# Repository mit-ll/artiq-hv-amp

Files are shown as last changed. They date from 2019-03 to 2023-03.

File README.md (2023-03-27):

# artiq-hv-amp

Schematic designs for a 1U rack mountable amplifier for the Zotino and Fastino. 

These are from the sinara family of DACs (https://github.com/sinara-hw/Zotino, https://github.com/sinara-hw/Fastino) and output 32 channels from -10 to +10 V and offer similar capabilities to the underlying AD9910 and AD9912 DACs from analog devices on which these cards are based. The amplifiers in this repository provide the following capabilities:

1. x4 amplification based on Linear's LTC6090 low noise HV amp.
2. Differential pair routing and differential inductors on all outputs.
3. MHz bandwidth and low output impedance.
4. Differentially paired HD68 input/output compatible with zotino, fastino.
5. ESD protection on all outputs with high speed low capacitance diodes.
6. Reverse polarity protection on high voltage input power.

DISTRIBUTION STATEMENT A. Approved for public release. Distribution is unlimited.

This material is based upon work supported under Air Force Contract No. FA8702-15-D-0001. Any opinions, findings, conclusions or recommendations expressed in this material are those of the author(s) and do not necessarily reflect the views of the U.S. Air Force.

© 2022 Massachusetts Institute of Technology.

Delivered to the U.S. Government with Unlimited Rights, as defined in DFARS Part 252.227-7013 or 7014 (Feb 2014). Notwithstanding any copyright notice, U.S. Government rights in this work are defined by DFARS 252.227-7013 or DFARS 252.227-7014 as detailed above. Use of this work other than as specifically authorized by the U.S. Government may violate any copyrights that exist in this work.

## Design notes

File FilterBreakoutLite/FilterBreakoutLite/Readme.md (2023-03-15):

This folder contains KiCAD models of filter boards for use with DAC signals arranged in groups of 32 differential pairs in an HD-68 cable.
Jules designed the original and manufactured it for Marlo and I (dreens) made more recent modifications to extend to the rest of the LL ions lab.

Key organizing principles:
1. A 'motherboard' takes 32 pairs as input, and offers a number of jumper selectable options.
2. One option is to utilize 8 four channel daughter boards inserted via card edge connectors.
3. Another option is to use on-board low-pass filters with 10 kHz cutoff and 12 dB/octave rolloff.
4. Coax pickoffs enable monitoring or over-riding channels on a case by case basis.
5. Grounds can be passed through to an HD-68 differential output, or shorted to board ground.
6. Filtered signals may be accessed either at this output HD-68, or via a DB-25 connector with the first 25 channels.
7. The FilterMotherboard folder contains the latest motherboard as well as some low-pass daughterboards, which weren't produced in light of the on-board LP option that was added.
8. The FilterDaughterboard-old folder contains daughterboards useful for shuttling with a higher cutoff frequency.

Known Issues:
1. The DB-25 output connector has a left-right mirroring issue. Best to resolve using ribbon cable to connect out to enclosure.
2. There's not really a way to utilize the 32 pin differentially paired output right now.
   One could imagine a future where we run differential pairs all the way to the octagon / internal vacuum circuitboard.
3. Be sure to review CAD related issues below.

CAD for the enclosure:
1. Successfull 1U rack mount ordered from protocase.
2. Key issue: rear screws off by exactly 0.5"- too close to the front panel by this amount.
3. Key issue: needs rear panel re-design for DB25 style cases instead of COTIAC mil-spec 32 pin.
4. Key issue: needs to be updated for 2U height for use with card-insertable motherboards.
5. This will entail obtaining a new template from protocase (the included design has as its base an imported model from protocase).

Ordering from protocase:
1. I've had success with two options so far, powder coated steel, and aluminum. Former is a bit cheaper but latter is a bit better.
2. Make sure to utilize their "PEM" fasteners as done here- these are self-clinching fasteners that can make board installation a breeze.
3. PEM CAD available from PENN engineering, also cross check protocase' list of in-stock PEMs.
4. Ask for the case to be powdercoat screened in a few places to ensure electrical connectivity across all panels.
5. They'll want you to proof everything.

Ordering boards from advanced circuits:
1. I can't remember right now. Bug me (dreens) and I'll dig up my order documentation. I had them do assy too which was great.

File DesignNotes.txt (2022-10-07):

Specs of the Zotino (https://github.com/sinara-hw/Zotino/wiki):
>Output impedance of DAC is 500ohm with 2.2nF in parallel
>Output amplifier: OPA197
>All together, the output of the DACs has a 3rd-order Butterworth response with 75kHz cutoff frequency

Options for amplifier:
>OPA454 [296-41370-1-ND] //highest voltage
>OPA542 [296-15965-1-ND]
>OPA445 [OPA445AU-ND] //the one from the old LL design

>D-Sub connector:
>>5787082-7 [A31814-ND]

General thoughts:
>Would it be possible to use a boost converter and drive the amps directly from the output of the Zotino?
>>Could check out the schematics for the Zotino to see how this is done without getting too much noise
>>[LT3471EDD#TRPBFCT-ND]

---

General notes about using KiCAD:
>Select a component and go to properties; from here you can edit the library reference to change the library that the symbol derives from
>http://docs.kicad-pcb.org/5.1.0/en/getting_started_in_kicad/getting_started_in_kicad.html
>It would appear that setting up the libraries I have done, by using path substitutions in (Preferences>Manage symbol libraries...) has succeeded in making the project portable

Still ToDo:
>[CRITICAL] Figure out if it's possible to have hierarchical layouts similar to the schematics
>>>https://forum.kicad.info/t/hierarchical-sheets-and-pcb/6053/5
>>>The trick seems to be to use the standalone version of the PCB editor, which allows you to append board designs with other PCB files.  Unclear how much time this is really going to save for me, but should look in to it.
>Figure out the best default connection for the unused pins of the OPA454
>[OPTIONAL] Figure out how to make a nice 3D model of the HD68 connector
>>>https://forum.kicad.info/t/where-to-start-with-3d-models-for-custom-parts/7185

Other links:
>https://forum.kicad.info/t/how-to-make-kicad-schematic-libraries-load-with-a-relative-path/2639/3
>https://learn.sparkfun.com/tutorials/beginners-guide-to-kicad/setting-up-schematic-component-libraries
>https://hackaday.com/2017/05/18/kicad-best-practises-library-management/

---

Notes from dreens:
-I've added protection diodes to the design- first of all polarity protection diodes on the power supply, and also 70 V steering diodes on the input to the amplifiers. 
-I wasn't able to protect the output for lack of high enough voltage diodes in a small enough form factor.
-I've also added u.FL pickoffs before the input to the amplifier to enable network analysis of the transfer function through the amps for shuttling predistortion computations.
-PCB Unlimited had trouble getting the differential chokes to solder. Something about the feet not being exposed enough? 
-I guess maybe they're laser heating the pads and couldn't get it to heat enough.

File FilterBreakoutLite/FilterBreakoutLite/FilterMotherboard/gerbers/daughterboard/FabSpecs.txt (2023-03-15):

Total layers = 4
Board dimensions = 1.05" x 1.11"
Board type = FR4
Board thickness = 0.062"
Outer copper wt. = 1.0 Oz
Inner copper wt. = 1.0 Oz
Min trace/space = 0.010"
Min hole dia. = 0.015"
Min annular ring width = 0.007"
Total drills = 20
Surface finish = Lead-free HAL with selective hard gold, 30 microinch (see GerberList.txt for selective gold layer)
Soldermask both sides = yes
Soldermask type = LPI
Soldermask color = green
Silkscreen color = white

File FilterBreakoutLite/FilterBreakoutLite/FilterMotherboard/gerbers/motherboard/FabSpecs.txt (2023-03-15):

Total layers = 4
Board dimensions = 4.21" x 2.72"
Board type = FR4
Board thickness = 0.062"
Outer copper wt. = 1.0 Oz
Inner copper wt. = 1.0 Oz
Min trace/space = 0.005"
Min hole dia. = 0.010" (can be microvias)
Min annular ring width = 0.005"
Total drills = 332
Surface finish = Not critical; use default
Soldermask both sides = yes
Soldermask type = LPI
Soldermask color = green
Silkscreen color = white

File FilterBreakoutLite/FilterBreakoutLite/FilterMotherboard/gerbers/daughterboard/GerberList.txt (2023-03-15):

File extension		Description

GM1			Board edge

DRL			Drill

GTL			Top Copper
G2			Interal layer #1
G3			Internal layer #2
GBL			Bottom Copper

GTG			Top selective gold
GBG			Bottom selective gold

GTS			Top soldermask
GBS			Bottom soldermask
GTO			Top silkscreen
GBO			Bottom silkscreen

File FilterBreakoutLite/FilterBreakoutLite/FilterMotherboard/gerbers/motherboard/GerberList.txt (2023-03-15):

File extension		Description

GM1			Board edge

DRL			Drill

GTL			Top Copper
G2			Interal layer #1
G3			Internal layer #2
GBL			Bottom Copper

GTS			Top soldermask
GBS			Bottom soldermask
GTO			Top silkscreen
GBO			Bottom silkscreen
GTP			Top paste	
GBP			Bottom paste

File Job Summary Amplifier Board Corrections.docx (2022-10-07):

Job: Update KiCAD amplifier schematic and prep BOM for assembly April 5th, 2022

Notes:

This work was completed by Arham one month ago, but key problems with the work were just discovered.

Tasks:

1. Two polarity reversal protection diodes were added. EGP51G-E3/CGICT-ND. As originally requested, “One should point from -V to ground, the other from ground to +V.”
  a. This task is not done correctly. The diodes have been added in series, which would create an unwanted diode drop on the power supply lines.

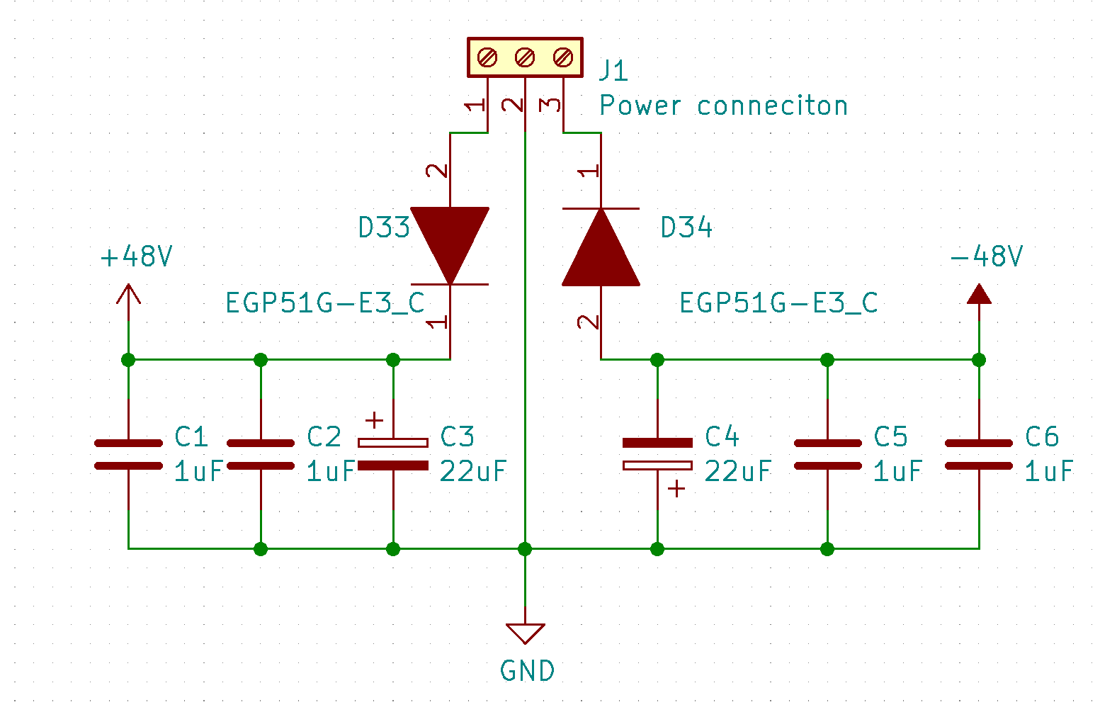
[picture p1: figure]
Machine generated alternative text: +48V EGP51G-E3 C 000 22uF GND Power conneciton EGP51G-E3 C 22uF

  b. They need to be in parallel with the buffer capacitors, in the reverse direction so as to ground the incorrectly applied voltage:

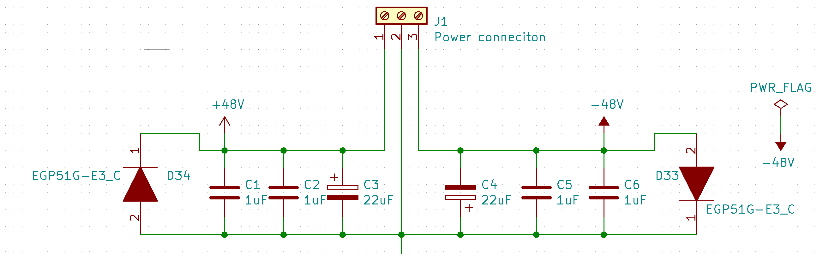
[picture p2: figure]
Machine generated alternative text: Power conneciton EGP51G-E3_C 000 +48V 22uF FLAG 22uF EGP51G-E3 C

2. On several of the blocks, copper pours did not connect properly. I count 11/32 channels with this problem.

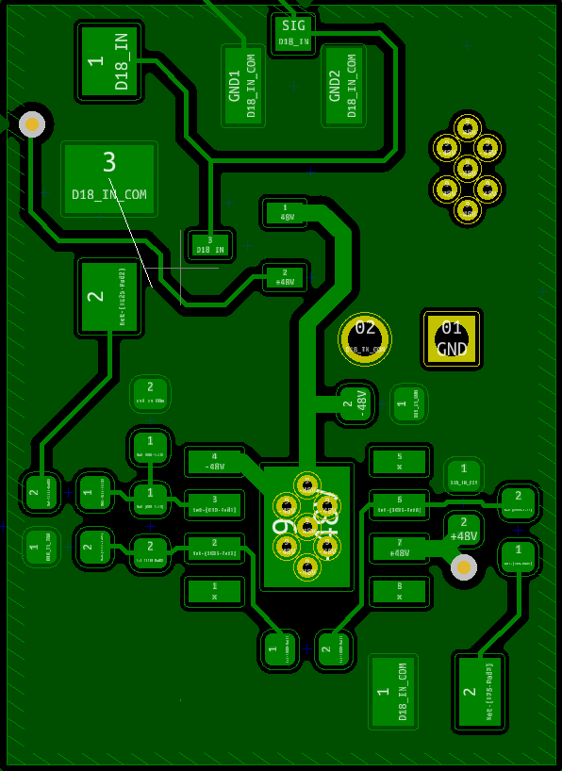
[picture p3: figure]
Machine generated alternative text: DIB 1 com

  a. Note the white line connecting from the #3 to the dangling pour. These white lines are always a sign of disconnected things and I’m not sure how they were missed.
  b. Note that one of the devices even grounds to this region of the copper pour, and thus will not function properly.
  c. Here is another example on the other side of the board:

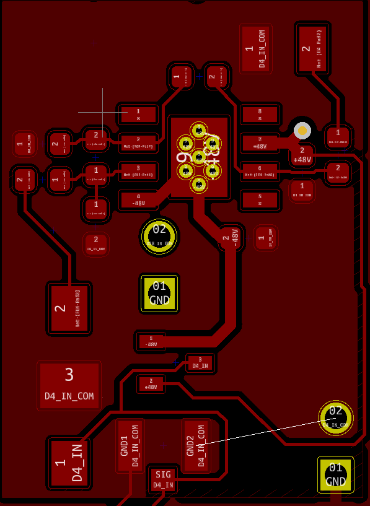
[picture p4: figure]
Machine generated alternative text: +48V +48V D4 IN com SIG

  d. See the white line connecting the left portion of the pour to the right portion. In this case, the bypass capacitors are prevented from working.

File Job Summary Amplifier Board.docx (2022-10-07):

Job: Update KiCAD amplifier schematic and prep BOM for assembly

Notes:

This layout uses repeating blocks. Some changes are required on the main board, others on the repeating blocks. Changes in the repeating blocks must be made in two places, “AmpBlock” and “AmpBlockFlipped”.

Tasks:

1. Add two polarity reversal protection diodes. EGP51G-E3/CGICT-ND. One should point from -V to ground, the other from ground to +V.
2. Add 1727-5056-2-ND steering diodes for protecting 32 inputs to op-amps. Fit in on repeating block. Pin 1 connects to amplifier block input, pin 2 connects to +48 V, pin 1 connects to -48 V.
3. Add coax pickoff H9161TR-ND to amplifier block input, ground the shield to INPUT_COM (not to GND).
4. Add optional grounding jumper ED3264-02-ND in four places on the main board, replacing what are now labeled as R259-262. Also replace the two grounding resistors on each block with a single grounding jumper. (in block 1, these are R193, R194).

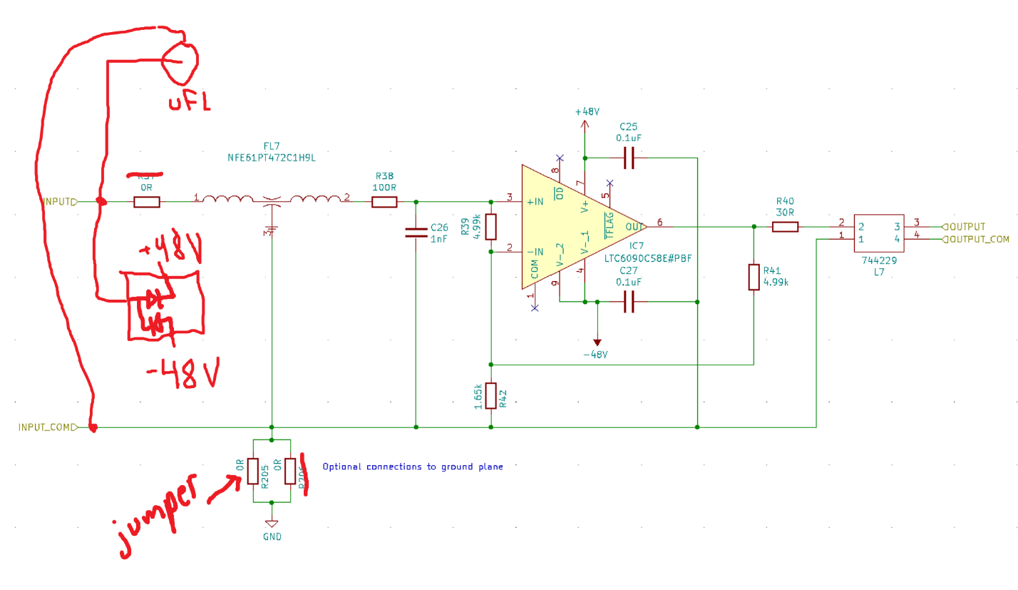
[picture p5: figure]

5. Layout and Route Board.
6. Prepare Gerbers.
7. Prepare BOM and CPL files based on provided component list. By the way, this file summarizes what I need to give to advanced circuits, my manufacturer: Advanced Circuits Board Assembly (http://www.4pcb.com/Assembly%20Requirements%20(1-5-2016).pdf). Here’s some discussion on how to get them from KiCAD in case it is new to you: generate-bom-and-centroid-file-from-kicad (https://support.jlcpcb.com/article/84-how-to-generate-the-bom-and-centroid-file-from-kicad).
8. Component List:
  a. Main Board:
    i. 277-1578-ND , 3 pin screw terminal, J1
    ii. A31814-ND, HD68 connector, J2-3
    iii. 1276-1838-1-ND, 1uF, C1-2,5-6
    iv. 565-1365-ND, 22uF, C3-4
    v. 565-3338-1-ND, 10uF, C103-118
    vi. RMCF0805ZT0R00CT-ND, 0k short, R257-258.
    vii. A30916-ND, 2-pin header, R259-262. (jumper, 609-6251-ND)
    viii. EGP51G-E3/CGICT-ND, diode, add to main board between +48 and GND, GND and -48
  b. Amp Block:
    i. 505-LTC6090CS8E#PBF-ND (mouser has more stock: 584-LTC6090CS8E#PBF), IC1
    ii. 1727-5056-2-ND, steering diode add between block input, +/-48 V.
    iii. H9161TR-ND, uFL coax pickoff, add at block input.
    iv. 1276-6807-1-ND, 0.1u, C7,9
    v. 1292-1380-1-ND, 1000p, C8
    vi. H11891TR-ND, u.FL connector
    vii. 490-2554-2-ND, EMI Filter, FL1
    viii. 311-100GRCT-ND, 100 ohm, R2
    ix. CR0603-FX-4991ELFCT-ND, 4.99k, R3, R5
    x. RMCF0603FT1K65CT-ND, 1.65k, R6
    xi. 738-RMCF0603FT30R0CT-ND, 30 ohm, R4
    xii. RMCF0603ZT0R00CT-ND, R3, L2, 0 ohm
    xiii. 732-1488-1-ND, common mode choke, L1
    xiv. A30916-ND, 2-pin header, in place of R193 and R194. (jumper, 609-6251-ND)
    xv. R1, remove from design

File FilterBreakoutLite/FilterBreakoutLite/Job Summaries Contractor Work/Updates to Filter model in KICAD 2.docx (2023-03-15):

KiCAD Filter model updates March 21st, 2022

Job Summary:

I’m hoping that Kristian Jordan can make a few updates to the design of filterboards and motherboards. The main changes desired relate to keeping signals differentially paired, and not having the negative pairs grounded on the board.

Job Details:

1. The output connector, which was previously changed to a 68 pin VHDCI just like the input, also needs to have negative pairs passed through as an option. The pin numbers need to match the input VHDCI, even though this will necessitate a large number of overlapping traces and vias. Previously I thought it would be acceptable to switch them, but I was incorrect.

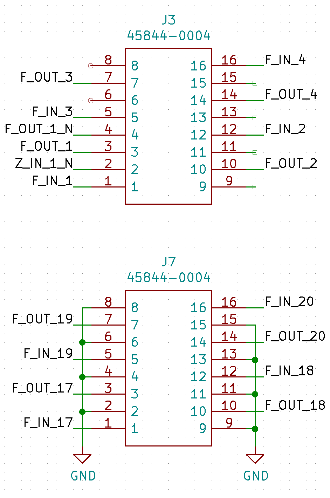
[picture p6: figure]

2. The daughter boards must be modified so that each channel’s paired negative signal is used as ground, and passed through to output. I’ve already made this change in the schematic for channel 1:

See Z_IN_1_N goes to pin 2 instead of GND ->

Not like this ->

3. The daughter boards still have two inner ground planes, these need to ground through a 10M resistor to one of the negative input signals.
4. The motherboards need a number of connectors added:
  a. Between the filter boards and the output, the positive signals should go through a jumper (0.1” header 2x32) so that they can be interrupted if desired. Please arrange these all in a row so that a 2x32 header array can be used. Feel free to increase board size.
  b. Similarly, the negative signals should go to the center of a 3 pin header, so that they can either be grounded or passed along to the output VHDCI. This means a large 3x32 header including all 32. Please arrange all in a row, increase board size in vertical direction so 68 pin connectors are farther from each other.
  c. After the jumpers, before the output VHDCI, the signals should go to a u.FL pickoff, positive on the center pin, negative on the outer shield. Leave a little more space for these, the wires come out sideways, and make sure they are in order. 4x8 is okay, but must go 1,2,3,4 in one row not 2,1,4,3.
  d. Positive Output Pins 1-25 should also go to a DB25 connector, as they used to in the older version of the motherboard. This connector should be added after all the jumpers, close to the output VHDCI68 connector.
5. The motherboards also need all RC filters removed.
6. All gerbers, and assy files (BOM, centroid, paste, assy drawing) need to be re-generated.

Motherboard Schematic for the 1st Channel:

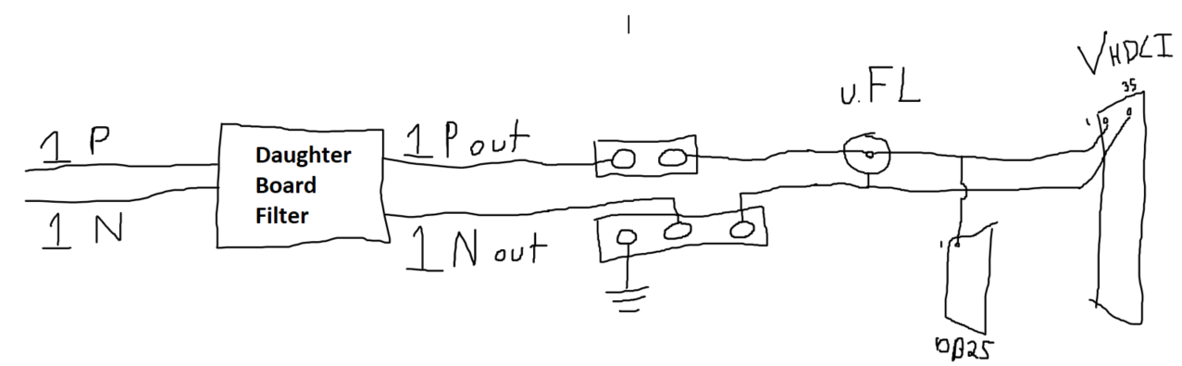
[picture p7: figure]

Part List: (still needs some updating!)

1. Motherboard:
  a. A31814-ND, HD68 connector, J1, J2
  b. WM7543-ND, board edge connector, J3-10
  c. RMCF0603ZT0R00CT-ND , R1-6, 13-18, 25-30, 39-44, 51-56, 63-66, 71,72: 0 ohm
  d. All other R’s, do not place.
  e. All C’s: do not place.
2. Daughterboard OLD:
  a. H11891TR-ND, u.FL connector
  b. 587-2511-1-ND, PI filter inductor, L1
  c. 311-69.8HRCT-ND, R2, 70 ohm
  d. 399-C0603C222J2GAC7867CT-ND, C2-3, 22n 100V NP0 0603
  e. RMCF0603ZT0R00CT-ND, R3, L2, 0 ohm
  f. C1, 587-6323-2-ND
  g. R1, do not place
  h. Same for other four filters.
3. Daughterboard NEW:
  a. RMCF0603JJ1K00TR-ND, R1,2,3,4: 1k
  b. 587-6323-2-ND, C1,2,3,4: 0.1u

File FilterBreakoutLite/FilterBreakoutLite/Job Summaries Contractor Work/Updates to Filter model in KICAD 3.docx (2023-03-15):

KiCAD Filter model updates March 21st, 2022

Job Summary:

I’m hoping that Kristian Jordan can make a few updates to the design of filterboards and motherboards. The main changes desired relate to keeping signals differentially paired, and not having the negative pairs grounded on the board.

Job Details:

1. The output connector, which was previously changed to a 68 pin VHDCI just like the input, also needs to have negative pairs passed through as an option. The pin numbers need to match the input VHDCI, even though this will necessitate a large number of overlapping traces and vias. Previously I thought it would be acceptable to switch them, but I was incorrect.


2. The daughter boards must be modified so that each channel’s paired negative signal is used as ground, and passed through to output. I’ve already made this change in the schematic for channel 1:

See Z_IN_1_N goes to pin 2 instead of GND ->

Not like this ->

3. The daughter boards still have two inner ground planes, these need to ground through a 10M resistor to one of the negative input signals.
4. The motherboards need a number of connectors added:
  a. Between the filter boards and the output, the positive signals should go through a jumper (0.1” header 2x32) so that they can be interrupted if desired. Please arrange these all in a row so that a 2x32 header array can be used. Feel free to increase board size.
  b. Similarly, the negative signals should go to the center of a 3 pin header, so that they can either be grounded or passed along to the output VHDCI. This means a large 3x32 header including all 32. Please arrange all in a row, increase board size in vertical direction so 68 pin connectors are farther from each other.
  c. After the jumpers, before the output VHDCI, the signals should go to a u.FL pickoff, positive on the center pin, negative on the outer shield. Leave a little more space for these, the wires come out sideways, and make sure they are in order. 4x8 is okay, but must go 1,2,3,4 in one row not 2,1,4,3.
  d. Positive Output Pins 1-25 should also go to a DB25 connector, as they used to in the older version of the motherboard. This connector should be added after all the jumpers, close to the output VHDCI68 connector.
5. The motherboards also need all RC filters removed.
6. All gerbers, and assy files (BOM, centroid, paste, assy drawing) need to be re-generated.

Motherboard Schematic for the 1st Channel:


Part List: (still needs some updating!)

1. Motherboard:
  a. A31814-ND, HD68 connector, J1, J2
  b. WM7543-ND, board edge connector, J3-10
  c. RMCF0603ZT0R00CT-ND , R1-6, 13-18, 25-30, 39-44, 51-56, 63-66, 71,72: 0 ohm
  d. All other R’s, do not place.
  e. All C’s: do not place.
2. Daughterboard OLD:
  a. H11891TR-ND, u.FL connector
  b. 587-2511-1-ND, PI filter inductor, L1
  c. 311-69.8HRCT-ND, R2, 70 ohm
  d. 399-C0603C222J2GAC7867CT-ND, C2-3, 22n 100V NP0 0603
  e. RMCF0603ZT0R00CT-ND, R3, L2, 0 ohm
  f. C1, 587-6323-2-ND
  g. R1, do not place
  h. Same for other four filters.
3. Daughterboard NEW:
  a. RMCF0603JJ1K00TR-ND, R1,2,3,4: 1k
  b. 587-6323-2-ND, C1,2,3,4: 0.1u

Updates 4/22/22

1. I have already explained these issues and written about them in BOLD in the modified document I attached ten days back, on Tuesday April 12th, see above. I will try and explain more clearly here.
2. I need the jumpers to be arranged in a grid, with 0.1” pitch both horizontal and vertical.
  a. This way I can really use a single 3x32 header (SAM12369-ND) and 2x32 header (ED1309-64-ND) for all of them.
  b. If I want to change the jumpers I can change them all at once by moving an upside down 2x32 socket (2553-2044-2X32G00RA-ND) with its leads pairwise soldered, from one part of the 3x32 to the other.
  c. I also need these to be arranged in order, 1-32.
3. I need the u.FL connectors to be rearranged so that they are in order.
  a. Right now they are this way:

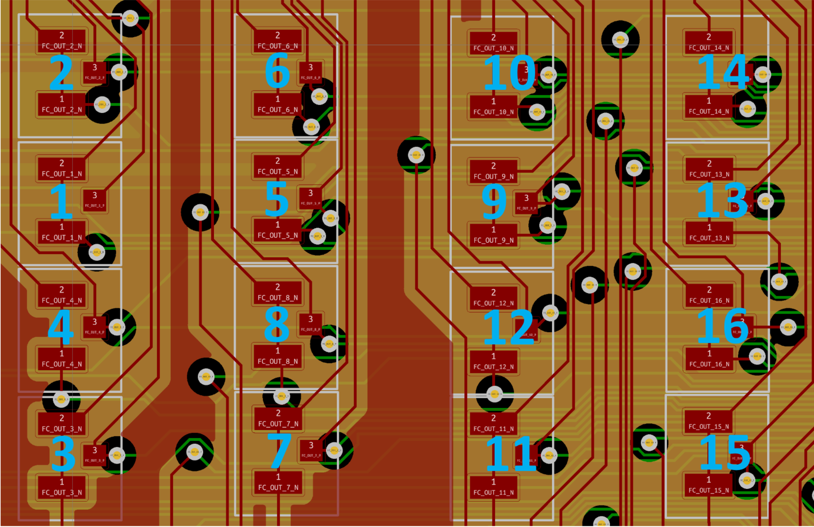
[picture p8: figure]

  b. I want them to look like this:

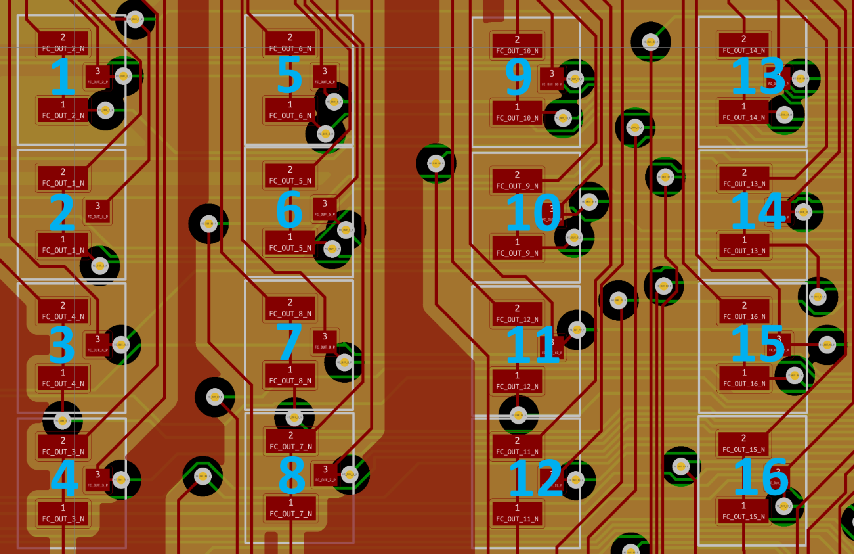
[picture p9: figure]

4. I need the silkscreen to include more labeling.
  a. These u.FL pickoffs need to be labeled 1-32.
  b. The 3x32 header needs #’s indicating which side is 1 and which side is 32, which row is GND and which row is N.
  c. The 2x32 header needs #’s indicating which side is 1 and which side is 32.
  d. Somewhere it should say “FilterMotherBoard V4.0, JS, DR, KJ, 04/22/22”
5. Daughterboards.
  a. The grounding still does not maintain differential pairing. I need the schematic to look like this, and keep the differential pairs separate and not shorted together. Otherwise what is the purpose of keeping them separate on the motherboard?? Notice how there

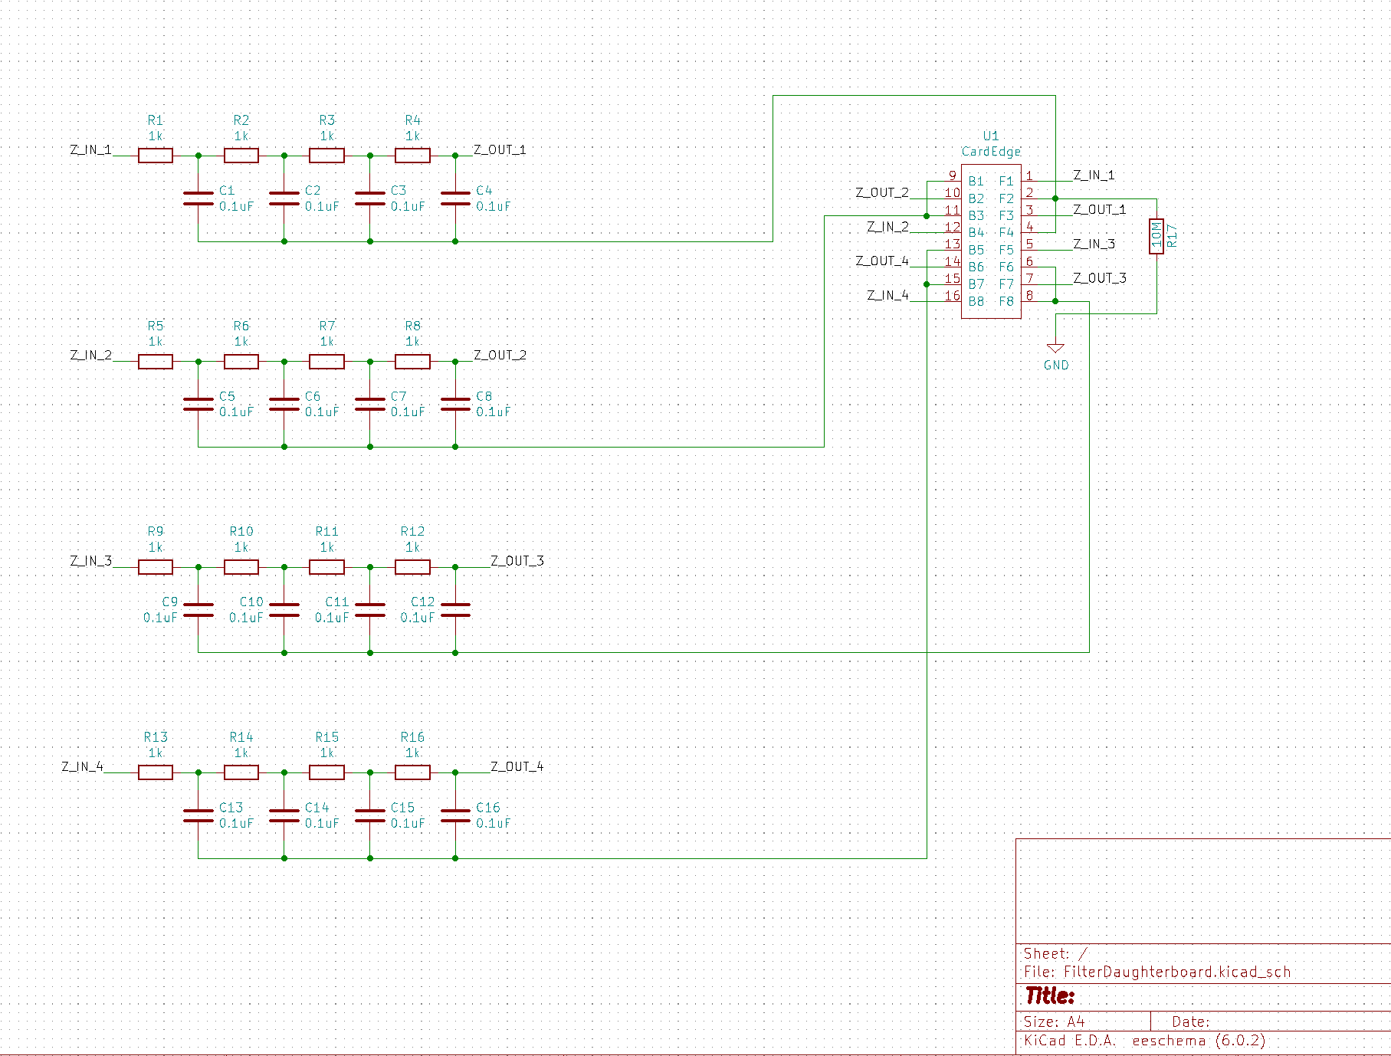
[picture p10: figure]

  b. I need the same thing for the old daughterboard. Right now looks like this:

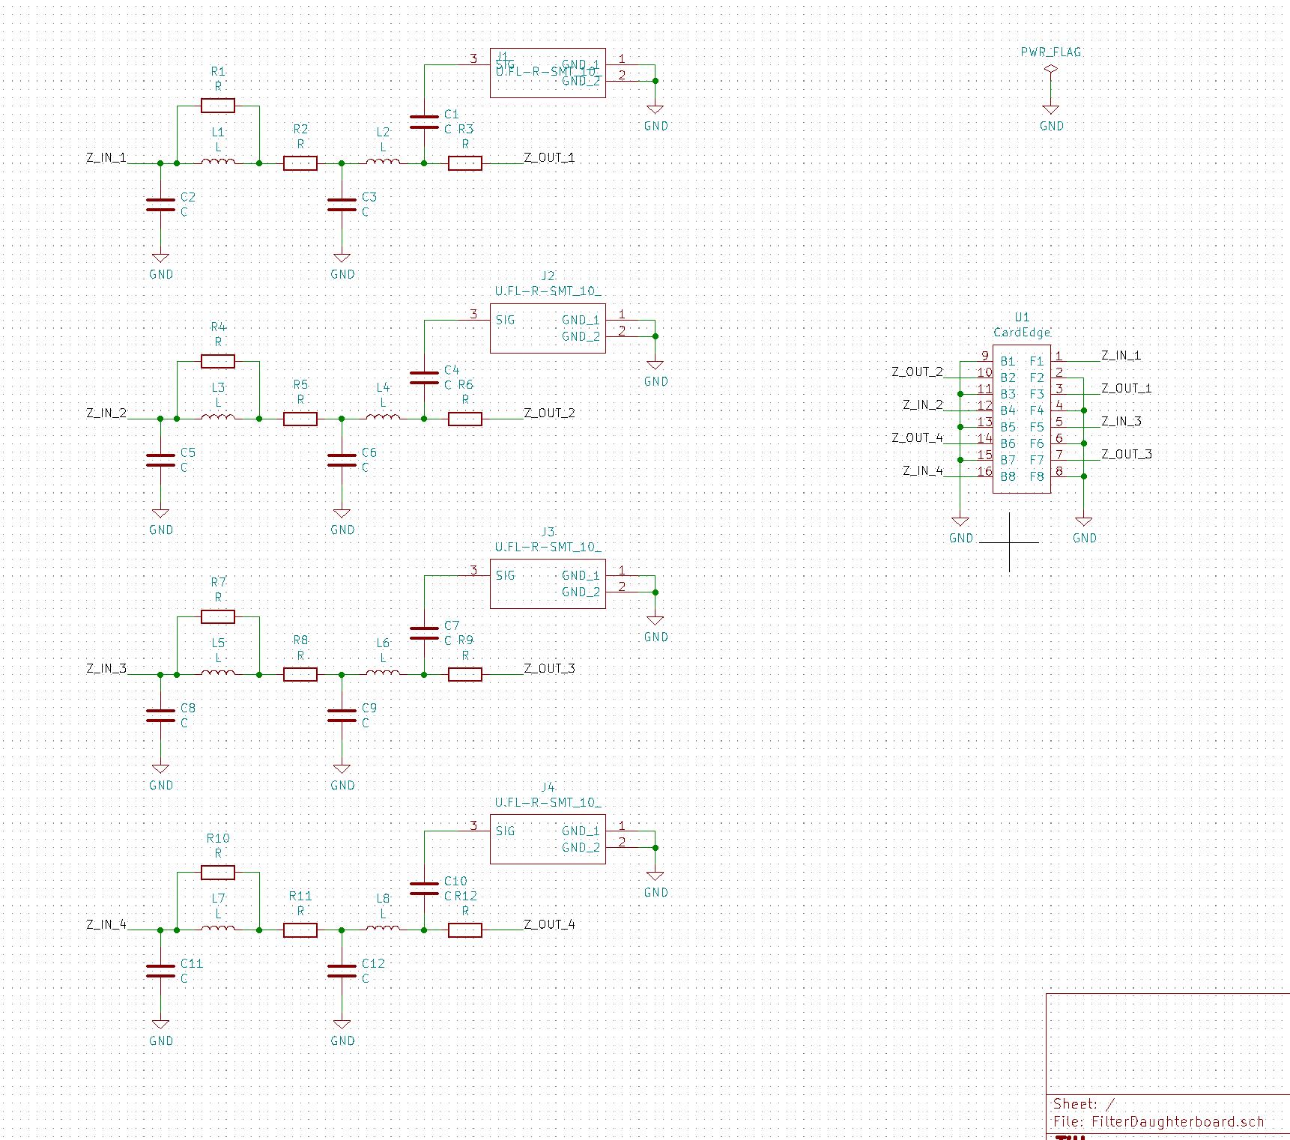
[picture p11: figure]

I need it to look like this:

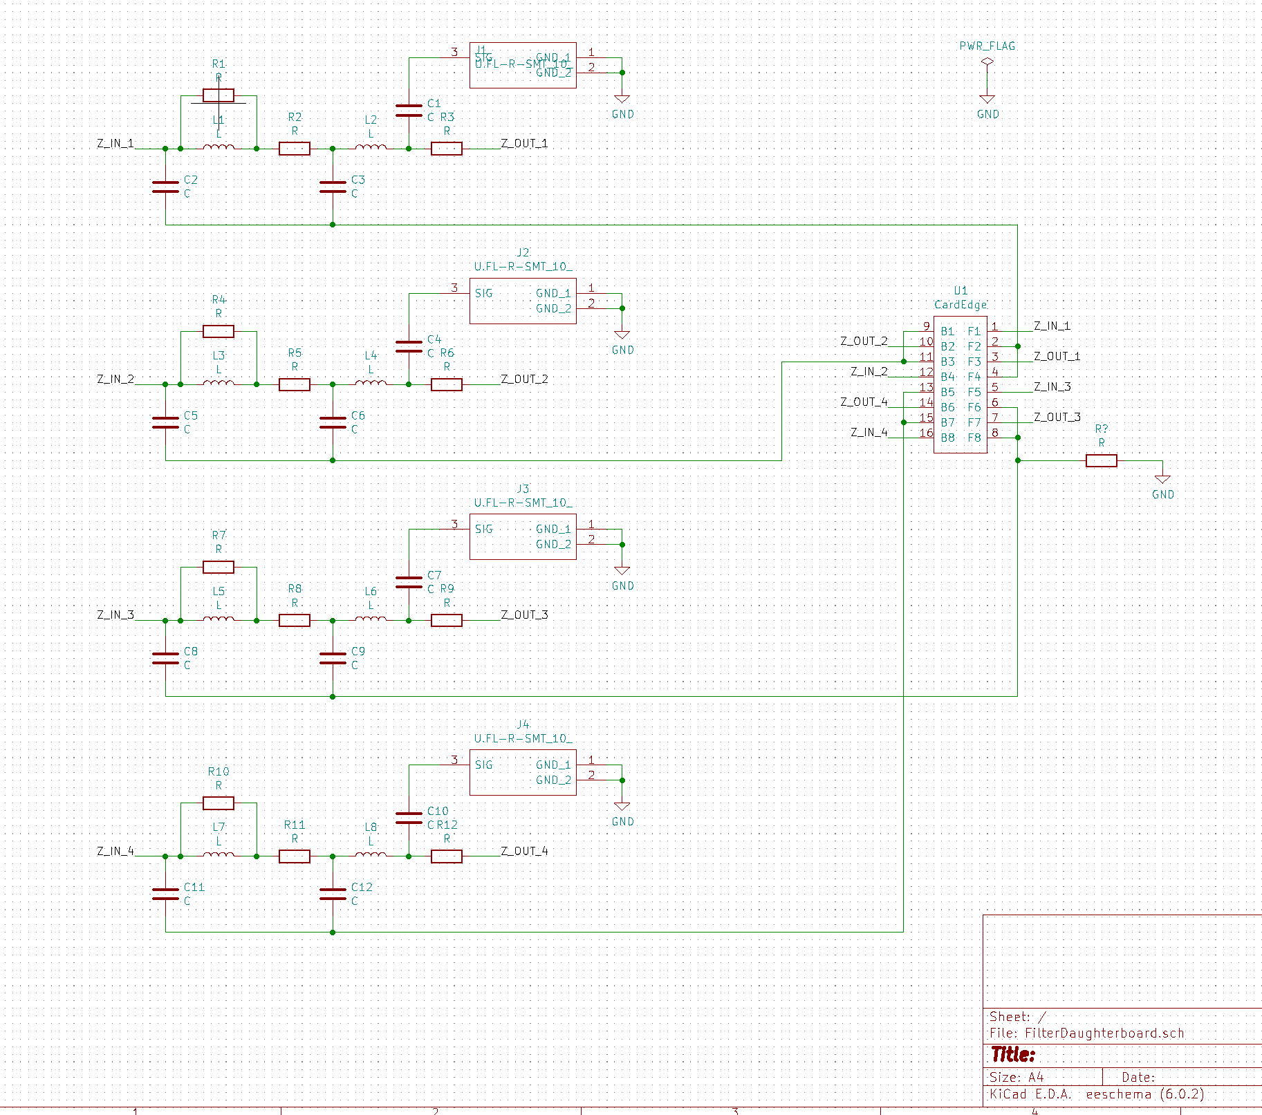
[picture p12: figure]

6. Please let me know if you would like to adjust the price on this work.
7. Thank you!

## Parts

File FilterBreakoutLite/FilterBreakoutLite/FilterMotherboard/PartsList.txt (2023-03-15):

H9161CT-ND		U.FL connector
	OR H11891TR-ND

587-2511-1-ND		Pi filter inductor

WM7543-ND		Board edge connector

182-825FE-ND		female socket db25 // mouser 636-182-025-213R181

A31814-ND		HD68 connector

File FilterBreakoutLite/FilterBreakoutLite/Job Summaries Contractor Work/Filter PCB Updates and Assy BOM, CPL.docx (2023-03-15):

Update KiCAD Filter model and prep BOM for assembly March 16th, 2022

Job Summary:

Seeking a PCB designer who can work in KiCAD to take an existing design and make a handful of changes described below. Also need a BOM prepared so that the board can be fully assembled by a vendor. The most compelling applicants will also coordinate the manufacture of ten boards (50 sub-boards) with advanced circuits, sierra circuits, or a preferred vendor offering assembly and comparable prices/leadtimes.

Job Details:

The design constitutes a primary board which routes 32 differentially paired inputs from a 68 pin VHDCI connector to eight 4-channel "daughter boards" where signals are filtered. 25 of the 32 channels are then sent out to a DB25 connector.

Desired changes:

1. The output connector will be changed to a 68 pin VHDCI just like the input, and all 32 channels should be used. The output from each filter should go to the same numbered pin on the output connector as the one that the "P" side of the differential input came in on. The unused channels on the 68 pin output connector should be grounded.

2. The daughter boards currently feature a 3-pole, 0.1 MHz Lowpass filter on each channel, as well as a U.FL coax pickoff. These will be prepped for assembly.

3. A new version of the daughter board will be made: U.FL pickoffs will be removed, and the filter replaced with a fourth order lowpass filter consisting of four cascaded passive RC stages, each with R=1k, C=0.1u. (Yes, rolloff will be slow, 3 dB point not where designed, but doesn't matter in this case).

Part List:

1. Motherboard:
  a. WM7543-ND, board edge connector, J1, J2
  b. A31814-ND, HD68 connector, J3-10
  c. RMCF0603ZT0R00CT-ND , R1-6, 13-18, 25-30, 39-44, 51-56, 63-66, 71,72: 0 ohm
  d. All other R’s, do not place.
  e. All C’s: do not place.
2. Daughterboard OLD:
  a. H11891TR-ND, u.FL connector
  b. 587-2511-1-ND, PI filter inductor, L1
  c. 311-69.8HRCT-ND, R2, 70 ohm
  d. 399-C0603C222J2GAC7867CT-ND, C2-3, 22n 100V NP0 0603
  e. RMCF0603ZT0R00CT-ND, R3, L2, 0 ohm
  f. C1, 587-6323-2-ND
  g. R1, do not place
  h. Same for other four filters.
3. Daughterboard NEW:
  a. RMCF0603JJ1K00TR-ND, R1,2,3,4: 1k
  b. 587-6323-2-ND, C1,2,3,4: 0.1u

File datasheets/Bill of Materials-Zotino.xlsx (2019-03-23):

Comment | Description | Designator | Footprint | Manufacturer | Manufacturer Part Number | Manufacturer1 ComponentHeight | Manufacturer1 Example | Manufacturer1 Part Number | Part Description | Part Number | Quantity
Plated Hole | Single Terminal Socket | B2, B3, B4, B8, B9, B10 | c130h80 |  |  |  |  |  | Plated Through Hole: Hole Dia.=0.8mm Pad Dia.=1.3mm, IPC-7251 Level C | PLATED_HOLE0.8_PAD1.3 | 6
Plated Hole | Single Terminal Socket | B5, B6 | c160h110 |  |  |  |  |  | Plated Through Hole: Hole Dia.=1.1mm Pad Dia.=1.6mm, IPC-7251 Level C | PLATED_HOLE1.1_PAD1.6 | 2
10uF | Polarised capacitor | C1, C2, C3, C7, C10, C12, C14, C47, C79, C90_1, C90_2, C90_3, C90_4, C90_5, C90_6, C90_7, C90_8, C90_9, C90_10, C90_11, C90_12, C90_13, C90_14, C90_15, C90_16, C90_17, C90_18, C90_19, C90_20, C90_21, C90_22, C90_23, C90_24, C90_25, C90_26, C90_27, C90_28, C90_29, C90_30, C90_31, C90_32, C93_1, C93_2, C93_3, C93_4, C93_5, C93_6, C93_7, C93_8, C93_9, C93_10, C93_11, C93_12, C93_13, C93_14, C93_15, C93_16, C93_17, C93_18, C93_19, C93_20, C93_21, C93_22, C93_23, C93_24, C93_25, C93_26, C93_27, C93_28, C93_29, C93_30, C93_31, C93_32, C124, C132, C134, C136, C147 | CAPMP3216X180N | AVX | TCJA106M016R0200 |  |  |  | ESR 0R200 Tantalum Solid Electrolytic Chip Capacitor with Conductive Polymer Electrode | CTE3216-18_10UF_16V_20%_AVX_TCJ | 78
100nF | Non-polarised capacitor | C4, C5, C9, C13, C19, C20, C21, C22, C23, C24, C31, C33, C38, C50, C53, C69, C70, C78, C83, C91_1, C91_2, C91_3, C91_4, C91_5, C91_6, C91_7, C91_8, C91_9, C91_10, C91_11, C91_12, C91_13, C91_14, C91_15, C91_16, C91_17, C91_18, C91_19, C91_20, C91_21, C91_22, C91_23, C91_24, C91_25, C91_26, C91_27, C91_28, C91_29, C91_30, C91_31, C91_32, C92_1, C92_2, C92_3, C92_4, C92_5, C92_6, C92_7, C92_8, C92_9, C92_10, C92_11, C92_12, C92_13, C92_14, C92_15, C92_16, C92_17, C92_18, C92_19, C92_20, C92_21, C92_22, C92_23, C92_24, C92_25, C92_26, C92_27, C92_28, C92_29, C92_30, C92_31, C92_32, C148, C150 | CAPC1005X55N | GENERIC | CC0402_100NF_16V_10%_X5R, CC0402_100NF_16V_10%_X5R, CC0402_100NF_16V_10%_X7R, CC0402_100NF_16V_10%_X7R, CC0402_100NF_16V_10%_X5R, CC0402_100NF_16V_10%_X5R, CC0402_100NF_16V_10%_X5R, CC0402_100NF_16V_10%_X5R, CC0402_100NF_16V_10%_X5R, CC0402_100NF_16V_10%_X5R, CC0402_100NF_16V_10%_X7R, CC0402_100NF_16V_10%_X7R, CC0402_100NF_16V_10%_X5R, CC0402_100NF_16V_10%_X7R, CC0402_100NF_16V_10%_X7R, CC0402_100NF_16V_10%_X5R, CC0402_100NF_16V_10%_X5R, CC0402_100NF_16V_10%_X7R, CC0402_100NF_16V_10%_X7R, CC0402_100NF_16V_10%_X7R, CC0402_100NF_16V_10%_X7R, CC0402_100NF_16V_10%_X7R, CC0402_100NF_16V_10%_X7R, CC0402_100NF_16V_10%_X7R, CC0402_100NF_16V_10%_X7R, CC0402_100NF_16V_10%_X7R, CC0402_100NF_16V_10%_X7R, CC0402_100NF_16V_10%_X7R, CC0402_100NF_16V_10%_X7R, CC0402_100NF_16V_10%_X7R, CC0402_100NF_16V_10%_X7R, CC0402_100NF_16V_10%_X7R, CC0402_100NF_16V_10%_X7R, CC0402_100NF_16V_10%_X7R, CC0402_100NF_16V_10%_X7R, CC0402_100NF_16V_10%_X7R, CC0402_100NF_16V_10%_X7R, CC0402_100NF_16V_10%_X7R, CC0402_100NF_16V_10%_X7R, CC0402_100NF_16V_10%_X7R, CC0402_100NF_16V_10%_X7R, CC0402_100NF_16V_10%_X7R, CC0402_100NF_16V_10%_X7R, CC0402_100NF_16V_10%_X7R, CC0402_100NF_16V_10%_X7R, CC0402_100NF_16V_10%_X7R, CC0402_100NF_16V_10%_X7R, CC0402_100NF_16V_10%_X7R, CC0402_100NF_16V_10%_X7R, CC0402_100NF_16V_10%_X7R, CC0402_100NF_16V_10%_X7R, CC0402_100NF_16V_10%_X7R, CC0402_100NF_16V_10%_X7R, CC0402_100NF_16V_10%_X7R, CC0402_100NF_16V_10%_X7R, CC0402_100NF_16V_10%_X7R, CC0402_100NF_16V_10%_X7R, CC0402_100NF_16V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 | 0.55mm | MURATA | GRM155R61C104KA88D, GRM155R61C104KA88D, GRM155R71C104KA88D, GRM155R71C104KA88D, GRM155R61C104KA88D, GRM155R61C104KA88D, GRM155R61C104KA88D, GRM155R61C104KA88D, GRM155R61C104KA88D, GRM155R61C104KA88D, GRM155R71C104KA88D, GRM155R71C104KA88D, GRM155R61C104KA88D, GRM155R71C104KA88D, GRM155R71C104KA88D, GRM155R61C104KA88D, GRM155R61C104KA88D, GRM155R71C104KA88D, GRM155R71C104KA88D, GRM155R71C104KA88D, GRM155R71C104KA88D, GRM155R71C104KA88D, GRM155R71C104KA88D, GRM155R71C104KA88D, GRM155R71C104KA88D, GRM155R71C104KA88D, GRM155R71C104KA88D, GRM155R71C104KA88D, GRM155R71C104KA88D, GRM155R71C104KA88D, GRM155R71C104KA88D, GRM155R71C104KA88D, GRM155R71C104KA88D, GRM155R71C104KA88D, GRM155R71C104KA88D, GRM155R71C104KA88D, GRM155R71C104KA88D, GRM155R71C104KA88D, GRM155R71C104KA88D, GRM155R71C104KA88D, GRM155R71C104KA88D, GRM155R71C104KA88D, GRM155R71C104KA88D, GRM155R71C104KA88D, GRM155R71C104KA88D, GRM155R71C104KA88D, GRM155R71C104KA88D, GRM155R71C104KA88D, GRM155R71C104KA88D, GRM155R71C104KA88D, GRM155R71C104KA88D, GRM155R71C104KA88D, GRM155R71C104KA88D, GRM155R71C104KA88D, GRM155R71C104KA88D, GRM155R71C104KA88D, GRM155R71C104KA88D, GRM155R71C104KA88D, GRM155R71C104KA88D, GRM155R71C104KA88D, GRM155R71C104KA88D, GRM155R71C104KA88D, GRM155R71C104KA88D, GRM155R71C104KA88D, GRM155R71C104KA88D, GRM155R71C104KA88D, GRM155R71C104KA88D, GRM155R71C104KA88D, GRM155R71C104KA88D, GRM155R71C104KA88D, GRM155R71C104KA88D, GRM155R71C104KA88D, GRM155R71C104KA88D, GRM155R71C104KA88D, GRM155R71C104KA88D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 | SMD Multilayer Chip Ceramic Capacitor | CC0402_100NF_16V_10%_X5R, CC0402_100NF_16V_10%_X5R, CC0402_100NF_16V_10%_X7R, CC0402_100NF_16V_10%_X7R, CC0402_100NF_16V_10%_X5R, CC0402_100NF_16V_10%_X5R, CC0402_100NF_16V_10%_X5R, CC0402_100NF_16V_10%_X5R, CC0402_100NF_16V_10%_X5R, CC0402_100NF_16V_10%_X5R, CC0402_100NF_16V_10%_X7R, CC0402_100NF_16V_10%_X7R, CC0402_100NF_16V_10%_X5R, CC0402_100NF_16V_10%_X7R, CC0402_100NF_16V_10%_X7R, CC0402_100NF_16V_10%_X5R, CC0402_100NF_16V_10%_X5R, CC0402_100NF_16V_10%_X7R, CC0402_100NF_16V_10%_X7R, CC0402_100NF_16V_10%_X7R, CC0402_100NF_16V_10%_X7R, CC0402_100NF_16V_10%_X7R, CC0402_100NF_16V_10%_X7R, CC0402_100NF_16V_10%_X7R, CC0402_100NF_16V_10%_X7R, CC0402_100NF_16V_10%_X7R, CC0402_100NF_16V_10%_X7R, CC0402_100NF_16V_10%_X7R, CC0402_100NF_16V_10%_X7R, CC0402_100NF_16V_10%_X7R, CC0402_100NF_16V_10%_X7R, CC0402_100NF_16V_10%_X7R, CC0402_100NF_16V_10%_X7R, CC0402_100NF_16V_10%_X7R, CC0402_100NF_16V_10%_X7R, CC0402_100NF_16V_10%_X7R, CC0402_100NF_16V_10%_X7R, CC0402_100NF_16V_10%_X7R, CC0402_100NF_16V_10%_X7R, CC0402_100NF_16V_10%_X7R, CC0402_100NF_16V_10%_X7R, CC0402_100NF_16V_10%_X7R, CC0402_100NF_16V_10%_X7R, CC0402_100NF_16V_10%_X7R, CC0402_100NF_16V_10%_X7R, CC0402_100NF_16V_10%_X7R, CC0402_100NF_16V_10%_X7R, CC0402_100NF_16V_10%_X7R, CC0402_100NF_16V_10%_X7R, CC0402_100NF_16V_10%_X7R, CC0402_100NF_16V_10%_X7R, CC0402_100NF_16V_10%_X7R, CC0402_100NF_16V_10%_X7R, CC0402_100NF_16V_10%_X7R, CC0402_100NF_16V_10%_X7R, CC0402_100NF_16V_10%_X7R, CC0402_100NF_16V_10%_X7R, CC0402_100NF_16V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 | 85
10nF | Non-polarised capacitor | C6, C64 | CAPC1608X87N | GENERIC | CC0603_10NF_50V_10%_X7R | 0.87mm | PHYCOMP | 223858615636 | SMD Multilayer Chip Ceramic Capacitor | CC0603_10NF_50V_10%_X7R | 2
22uF | Non-polarised capacitor | C8, C129, C130, C131, C137, C138, C139, C140, C141, C142, C149, C151 | CAPC2012X135N | GENERIC | CC0805_22UF_16V_10%_X5R | 1.35mm | TDK | C2012X5R1C226KT | SMD Multilayer Chip Ceramic Capacitor | CC0805_22UF_16V_10%_X5R | 12
680pF | Non-polarised capacitor | C56_1, C56_2, C56_3, C56_4, C56_5, C56_6, C56_7, C56_8, C56_9, C56_10, C56_11, C56_12, C56_13, C56_14, C56_15, C56_16, C56_17, C56_18, C56_19, C56_20, C56_21, C56_22, C56_23, C56_24, C56_25, C56_26, C56_27, C56_28, C56_29, C56_30, C56_31, C56_32 | CAPC2012X135N | GENERIC | CC0805_680PF_50V_5%_NP0 | 1.35mm | PHYCOMP | 223886115681 | SMD Multilayer Chip Ceramic Capacitor | CC0805_680PF_50V_5%_NP0 | 32
220pF | Non-polarised capacitor | C61_1, C61_2, C61_3, C61_4, C61_5, C61_6, C61_7, C61_8, C61_9, C61_10, C61_11, C61_12, C61_13, C61_14, C61_15, C61_16, C61_17, C61_18, C61_19, C61_20, C61_21, C61_22, C61_23, C61_24, C61_25, C61_26, C61_27, C61_28, C61_29, C61_30, C61_31, C61_32 | CAPC1608X87N | GENERIC | CC0603_220PF_50V_5%_NP0 | 0.87mm | PHYCOMP | 223886715221 | SMD Multilayer Chip Ceramic Capacitor | CC0603_220PF_50V_5%_NP0 | 32
2.2nF | Non-polarised capacitor | C62_1, C62_2, C62_3, C62_4, C62_5, C62_6, C62_7, C62_8, C62_9, C62_10, C62_11, C62_12, C62_13, C62_14, C62_15, C62_16, C62_17, C62_18, C62_19, C62_20, C62_21, C62_22, C62_23, C62_24, C62_25, C62_26, C62_27, C62_28, C62_29, C62_30, C62_31, C62_32 | CAPC3216X140N | GENERIC | CC1206_2.2NF_50V_5%_NP0 | 1.25mm | PHYCOMP | 2238 863 15222 | SMD Multilayer Chip Ceramic Capacitor | CC1206_2.2NF_50V_5%_NP0 | 32
1uF | Non-polarised capacitor | C63, C82, C96, C133, C144 | CAPC1608X87N | GENERIC | CC0603_1UF_25V_10%_X7R | 0.9mm | MURATA | GRM188R71E105KA12D | SMD Multilayer Chip Ceramic Capacitor | CC0603_1UF_25V_10%_X7R | 5
82pF | Non-polarised capacitor | C68, C71, C76, C77, C95 | CAPC1608X87N | GENERIC | CC0603_82PF_50V_5%_NP0 | 0.87mm | PHYCOMP | 223886715829 | SMD Multilayer Chip Ceramic Capacitor | CC0603_82PF_50V_5%_NP0 | 5
2.2uF | Non-polarised capacitor | C80, C81 | CAPC1608X87N | GENERIC | CC0603_2.2UF_16V_10%_X5R | 0.9mm | YAGEO | CC0603KRX5R7BB225 | SMD Multilayer Chip Ceramic Capacitor | CC0603_2.2UF_16V_10%_X5R | 2
S1411-46R | Surface Mount Clip for PCB Screening Covers | CLIP27, CLIP28, CLIP29, CLIP30, CLIP31, CLIP32, CLIP33, CLIP34, CLIP35, CLIP36, CLIP37, CLIP38, CLIP39, CLIP40, CLIP41, CLIP42, CLIP43, CLIP44, CLIP45, CLIP46, CLIP47, CLIP48, CLIP49, CLIP50, CLIP51, CLIP52 | CLIP_HOLLAND-SHIELDING_LC | HARWIN | S1411-46R |  |  |  | Surface Mount Clip for PCB Screening Covers, 1500 Serie | S1411-46R | 26
BAV199 | Serial Diode | D5_1, D5_2, D5_3, D5_4, D5_5, D5_6, D5_7, D5_8, D5_9, D5_10, D5_11, D5_12, D5_13, D5_14, D5_15, D5_16, D5_17, D5_18, D5_19, D5_20, D5_21, D5_22, D5_23, D5_24, D5_25, D5_26, D5_27, D5_28, D5_29, D5_30, D5_31, D5_32 | SOT95P240X110-3N | NXP SEMICONDUCTORS | BAV199 |  |  |  | Low-Leakage Double Diode | BAV199 | 32
SMBJ12A | Zener Diode | D10, D11 | DIOM5336X265N | FAIRCHILD SEMICONDUCTOR | SMBJ12A |  |  |  | Uni-Directional Transient Voltage Suppressor Diode | SMBJ12A | 2
160mA-48V | Fuse | F1, F2 | FUSRC3216X100N | TYCO ELECTRONICS | nanoSMDC016F |  |  |  | PolySwitch® PTC Overcurrent Protection Device | FUSR1206_TYCO-NANOSMD016F | 2
Use only in PCB | Fiducial Target | FTG1 | FIDUCIAL_TOP_C100-200 |  |  |  |  |  | Round Fiducial Target, Top Layer, 1.0mm, Top Solder 2.0mm, Keepout =2.0mm | FIDUCIAL_TARGET_C100-200 | 1
Use only in PCB | Fiducial Target | FTG2, FTG4 | FIDUCIAL_TOP_S100-200 |  |  |  |  |  | Square Fiducial Target, Top Layer, 1.0mm, Top Solder 2.0mm, Keepout =2.0mm | FIDUCIAL_TARGET_S100-200 | 2
Use only in PCB | Fiducial Target | FTG3 | FIDUCIAL_TOP_S200-400 |  |  |  |  |  | Square Fiducial Target, Top Layer, 2.0mm, Top Solder 4.0mm, Keepout =4.0mm | FIDUCIAL_TARGET_S200-400 | 1
Heat Sink No Pad | Heat Sink Without Pad | HS1 | HSINK_ATS_ATS-X50190G-C1-R0 | ADVENCED THERMAL SOLUTION (ATS) | ATS-X50190G-C1-R0 |  |  |  | 35.0 x 35.0 x 7.5 mm BGA Heat Sink - High Performance maxiFLOW/maxiGRIP-STD | HSINK_ATS_ATS-X50190G-C1-R0 | 1
CC6-1212DF-E | CONV DC/DC 6W DUAL 12V +-12V PCB | IC1 | CC6-1212DF-E | TDK-Lambda Americas Inc. | CC6-1212DF-E |  |  |  | CONV DC/DC 6W DUAL 12V +-12V PCB | CC6-1212DF-E | 1
OPA197ID | 36-V, Precision, Rail-to-Rail Input/Output, Low Offset Voltage, Operational Amplifiers | IC2_1, IC2_2, IC2_3, IC2_4, IC2_5, IC2_6, IC2_7, IC2_8, IC2_9, IC2_10, IC2_11, IC2_12, IC2_13, IC2_14, IC2_15, IC2_16, IC2_17, IC2_18, IC2_19, IC2_20, IC2_21, IC2_22, IC2_23, IC2_24, IC2_25, IC2_26, IC2_27, IC2_28, IC2_29, IC2_30, IC2_31, IC2_32 | SOIC127P600X175-8N | TEXAS INSTRUMENTS | OPA197ID |  |  |  | 36-V, Precision, Rail-to-Rail Input/Output, Low Offset Voltage, Operational Amplifiers | OPA197ID | 32
MAX6250ACSA+ | 1ppm/°C, Low-Noise, Precision, +5.000V Voltage Reference | IC3 | SOIC127P600X175-8N | MAXIM | MAX6250ACSA+ |  |  |  | 1ppm/°C, Low-Noise, Precision, +5.000V Voltage Reference | MAX6250ACSA+ | 1
LT1964ES5-BYP#TRMPBF | 200mA, Low Noise, Low Dropout Negative Micropower Regulator | IC4 | SOT95P280X100-5N | LINEAR TECHNOLOGY | LT1964ES5-BYP#TRMPBF |  |  |  | -1.22V to -20V, 200mA, Low Noise, Low Dropout Negative Micropower Regulator | LT1964ES5-BYP#TRMPBF | 1
SN65MLVD040RGZT | 4-Channel Half-Duplex M-LVDS Line Transceiver | IC8, IC9 | QFN50P700X700X100-49N-S420 | TEXAS INSTRUMENTS | SN65MLVD040RGZT |  |  |  | 4-Channel Half-Duplex M-LVDS Line Transceiver | SN65MLVD040RGZT | 2
AD5372BCPZ | 32-Channel, 16-Bit, Serial Input, Voltage Output Digital-to-Analog Converter | IC18 | QFN50P900X900X100-65N-S725 | ANALOG DEVICES | AD5372BCPZ |  |  |  | 32-Channel, 16-Bit, Serial Input, Voltage Output Digital-to-Analog Converter | AD5372BCPZ | 1
STM811SW16F | Microprocessor Reset Circuit | IC19 | SOT143N | ST MICROELECTRONICS | STM811SW16F |  |  |  | 2.93V Reset Threshold Voltage Microprocessor Reset Circuit | STM811SW16F | 1
SN74LV595APWT | 8-Bit Shift Register With 3-State Output Register | IC23 | SOP65P640X120-16N | TEXAS INSTRUMENTS | SN74LV595APWT |  |  |  | 8-Bit Shift Register With 3-State Output Register | SN74LV595APWT | 1
LT1763CS8#PBF | 1.22V to 20V 500mA, Low Noise, LDO Adjustable Micropower Regulator | IC27 | SOIC127P600X175-8N | LINEAR TECHNOLOGY | LT1763CS8#PBF |  |  |  | 1.22V to 20V 500mA, Low Noise, LDO Adjustable Micropower Regulator | LT1763CS8#PBF | 1
24AA02E48T-I/OT | 1.7V-5.5V, 2K I2C Serial EEPROM With EUI-48 Node Identity | IC32 | SOT95P280X145-5N | MICROCHIP TECHNOLOGY | 24AA02E48T-I/OT |  |  |  | 1.7V-5.5V, 2K I2C Serial EEPROM With EUI-48 Node Identity | 24AA02E48T-I/OT | 1
TPS62175DQC | 4.75-28VDC to 1-6VDC, 500mA Step-Down Converter With Sleep Mode | IC35 | SON50P200X300X80-11N-R94X250 | TEXAS INSTRUMENTS | TPS62175DQC |  |  |  | 4.75-28VDC to 1-6VDC, 500mA Step-Down Converter With Sleep Mode | TPS62175DQC | 1
D-SUB | 68 contacts, AMPLIMITE .050", Right Angled Receptacle Series III | J1 | TYCO_5787082-7 | TYCO ELECTRONICS | 5787082-7 |  |  |  | 68 contacts, AMPLIMITE .050", Right Angled Receptacle Series III | TYCO_5787082-7 | 1
Header 16 | Connector 16 Male | J2 | 3M_N2516-6002RB | 3M | N2516-6002RB |  |  |  | 16 Contacts - Straight .100'' x .100'' Low Profile Four-Wall Header, 2500 Series | 3M_N2516-6002RB | 1
Header 26 | Connector 26 Male | J3, J4, J5, J7 | 3M_N2526-6002RB | 3M | N2526-6002RB |  |  |  | 26 Contacts - Straight .100'' x .100'' Low Profile Four-Wall Header, 2500 Series | 3M_N2526-6002RB | 4
Familly | Connector 30 Male | J37 | 3M_N2530-6002RB | 3M | N2530-6002RB |  |  |  | 30 Contacts - Straight .100'' x .100'' Low Profile Four-Wall Header, 2500 Series | 3M_N2530-6002RB | 1
10uH | Inductor With Core | L1, L6, L7, L8, L9, L15, L16 | IND_MURATA-PS_8400 | MURATA POWER SOLUTIONS | 84103C |  |  |  | Miniature Surface Mount Power Inductor (8400 Serie) | IND_10UH_10%_MURATA-PS_8400 | 7
2x6.5mH | Inductor Common Mode | L4_1, L4_2, L4_3, L4_4, L4_5, L4_6, L4_7, L4_8, L4_9, L4_10, L4_11, L4_12, L4_13, L4_14, L4_15, L4_16, L4_17, L4_18, L4_19, L4_20, L4_21, L4_22, L4_23, L4_24, L4_25, L4_26, L4_27, L4_28, L4_29, L4_30, L4_31, L4_32 | IND_WURTH_WE-SL2 | WURTH ELEKTRONIK | 744229 |  |  |  | Common Mode SMD Line Filter (WE-SL2 Serie) | IND_6.5MH_50%_WURTH_WE-SL2-744229 | 32
Green | LED x4 Green 1C2A-BOT_3C4A_5C6A_7C8A-TOP | LD4, LD5 | LED_BIVAR_H485CGDL | BIVAR | H485CGDL |  |  |  | Quad-Level 2mm Green LED, PCB Edge Mounting | LED_BIVAR_H485CGDL | 2
Undefined | Resistor | R1, R15, R26, R27, R68_1, R68_2, R68_3, R68_4, R68_5, R68_6, R68_7, R68_8, R68_9, R68_10, R68_11, R68_12, R68_13, R68_14, R68_15, R68_16, R68_17, R68_18, R68_19, R68_20, R68_21, R68_22, R68_23, R68_24, R68_25, R68_26, R68_27, R68_28, R68_29, R68_30, R68_31, R68_32 | RESC1608X55N | Undefined | R0603_NO-VALUE | Undefined | Undefined | Undefined | Reserved Footprint For a 0603 (1608) Chip Resistor | R0603_NO-VALUE | 36
0 | Resistor | R2, R3, R11, R13, R14, R51, R88, R97, R99, R101 | RESC1005X40N | GENERIC | R0402_0R_JUMPER | 0.4mm | YAGEO PHYCOMP | 232270591001L | 1A (0.05R Max DC Resistance) Zero Ohm Jumper | R0402_0R_JUMPER | 10
36 | Resistor - 1% | R4 | RESC1608X55N | GENERIC | R0603_36R_1%_0.1W_100PPM | 0.55mm | NIC COMPONENT | NRC06F36R0TRF | General Purpose Thick Film Chip Resistor | R0603_36R_1%_0.1W_100PPM | 1
1k | Resistor - 1% | R5_1, R5_2, R5_3, R5_4, R5_5, R5_6, R5_7, R5_8, R5_9, R5_10, R5_11, R5_12, R5_13, R5_14, R5_15, R5_16, R5_17, R5_18, R5_19, R5_20, R5_21, R5_22, R5_23, R5_24, R5_25, R5_26, R5_27, R5_28, R5_29, R5_30, R5_31, R5_32, R7_1, R7_2, R7_3, R7_4, R7_5, R7_6, R7_7, R7_8, R7_9, R7_10, R7_11, R7_12, R7_13, R7_14, R7_15, R7_16, R7_17, R7_18, R7_19, R7_20, R7_21, R7_22, R7_23, R7_24, R7_25, R7_26, R7_27, R7_28, R7_29, R7_30, R7_31, R7_32 | RESC1608X55N | GENERIC | R0603_1K_1%_0.1W_100PPM | 0.55mm | NIC COMPONENT | NRC06F1001TRF | General Purpose Thick Film Chip Resistor | R0603_1K_1%_0.1W_100PPM | 64
100 | Resistor - 1% | R6, R16, R17, R18, R19, R20, R21, R22, R23, R141, R144, R147, R151, R157, R160, R163, R166, R170 | RESC1005X40N | GENERIC | R0402_100R_1%_0.1W_100PPM_50V | 0.4mm | PANASONIC | ERJ2RKF1000X | General Purpose Thick Film Chip Resistor | R0402_100R_1%_0.1W_100PPM | 18
220 | Resistor - 1% | R8, R9, R10, R12, R58, R82, R113, R114, R115, R116, R117, R118, R119, R120, R121, R122, R123 | RESC1608X55N | GENERIC | R0603_220R_1%_0.1W_100PPM | 0.55mm | NIC COMPONENT | NRC06F2200TRF | General Purpose Thick Film Chip Resistor | R0603_220R_1%_0.1W_100PPM | 17
2k32 | Resistor - 0.1% | R24_1, R24_2, R24_3, R24_4, R24_5, R24_6, R24_7, R24_8, R24_9, R24_10, R24_11, R24_12, R24_13, R24_14, R24_15, R24_16, R24_17, R24_18, R24_19, R24_20, R24_21, R24_22, R24_23, R24_24, R24_25, R24_26, R24_27, R24_28, R24_29, R24_30, R24_31, R24_32 | RESC1608X55N | GENERIC | R0603_2K32_0.1%_0.063W_10PPM | 0.5mm | TYCO HOLSWORTHY | RN73C1J2K32BTDF | Thin Film Chip Resistor | R0603_2K32_0.1%_0.063W_10PPM | 32
9k09 | Resistor - 0.1% | R25_1, R25_2, R25_3, R25_4, R25_5, R25_6, R25_7, R25_8, R25_9, R25_10, R25_11, R25_12, R25_13, R25_14, R25_15, R25_16, R25_17, R25_18, R25_19, R25_20, R25_21, R25_22, R25_23, R25_24, R25_25, R25_26, R25_27, R25_28, R25_29, R25_30, R25_31, R25_32 | RESC1608X55N | GENERIC | R0603_9K09_0.1%_0.063W_10PPM | 0.5mm | TYCO HOLSWORTHY | RN73C1J9K09BTDF | Thin Film Chip Resistor | R0603_9K09_0.1%_0.063W_10PPM | 32
11k | Resistor - 1% | R67_1, R67_2, R67_3, R67_4, R67_5, R67_6, R67_7, R67_8, R67_9, R67_10, R67_11, R67_12, R67_13, R67_14, R67_15, R67_16, R67_17, R67_18, R67_19, R67_20, R67_21, R67_22, R67_23, R67_24, R67_25, R67_26, R67_27, R67_28, R67_29, R67_30, R67_31, R67_32 | RESC1608X55N | GENERIC | R0603_11K_1%_0.1W_100PPM | 0.55mm | NIC COMPONENT | NRC06F1102TRF | General Purpose Thick Film Chip Resistor | R0603_11K_1%_0.1W_100PPM | 32
24k | Resistor - 1% | R69, R150 | RESC1608X55N | GENERIC | R0603_24K_1%_0.1W_100PPM | 0.55mm | NIC COMPONENT | NRC06F2402TRF | General Purpose Thick Film Chip Resistor | R0603_24K_1%_0.1W_100PPM | 2
2k7 | Resistor - 1% | R70, R153 | RESC1608X55N | GENERIC | R0603_2K7_1%_0.1W_100PPM | 0.55mm | YAGEO PHYCOMP | RC0603FR-072K7L | General Purpose Thick Film Chip Resistor | R0603_2K7_1%_0.1W_100PPM | 2
270k | Resistor - 1% | R162 | RESC1608X55N | GENERIC | R0603_270K_1%_0.1W_100PPM | 0.55mm | NIC COMPONENT | NRC06F2703TRF | General Purpose Thick Film Chip Resistor | R0603_270K_1%_0.1W_100PPM | 1
82k | Resistor - 1% | R164 | RESC1608X55N | GENERIC | R0603_82K_1%_0.1W_100PPM | 0.55mm | NIC COMPONENT | NRC06F8202TRF | General Purpose Thick Film Chip Resistor | R0603_82K_1%_0.1W_100PPM | 1
10k | Resistor - 1% | R171 | RESC1005X40N | GENERIC | R0402_10K_1%_0.0625W_100PPM | 0.4mm | YAGEO PHYCOMP | 232270671003L | General Purpose Thick Film Chip Resistor | R0402_10K_1%_0.0625W_100PPM | 1
10k | Thermistor NTC (Negative Temperature Coefficient) | RT1 | THERMC1608X90N | EPCOS | B57330V2103J260 |  |  |  | SMD NTC Thermistor for Temperature Measurement | THERM_NTC_10K_EPCOS_B57330V2103J260 | 1
CP20147H | Peltier Module 15x15 mm | TEC1 | TEC_CP20147H |  |  |  |  |  |  |  | 1
Test Point | Test Point | TP1, TP2, TP3, TP4, TP5, TP6, TP7, TP8, TP9, TP10, TP11, TP12, TP13, TP14, TP15, TP16, TP17, TP18 | TPS127 |  |  |  |  |  | 1.27mm x 1.27mm PCB Copper Area (SMD Test Point) | SMD_PAD_1.27X1.27MM | 18

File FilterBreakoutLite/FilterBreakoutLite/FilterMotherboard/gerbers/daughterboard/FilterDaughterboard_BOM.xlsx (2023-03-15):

Date: | 2022-02-27 15:47
Component Count: | 32
Ref | Qnty | Value | Datasheet | Footprint | Manufacturer Name | Digi-Key_PN | MPN | Description
C1, C2, C3, C4, C5, C6, C7, C8, C9, C10, C11, C12, C13, C14, C15, C16, | 16 | 0.1uF | https://ds.yuden.co.jp/TYCOMPAS/ut/detail?pn=HMK107B7104MA-T%20&u=M | Capacitor_SMD:C_0603_1608Metric | Taiyo Yuden | 587-6323-2-ND | HMK107B7104MA-T | CAP CER 0.1UF 100V X7R 0603
R1, R2, R3, R4, R5, R6, R7, R8, R9, R10, R11, R12, R13, R14, R15, R16, | 16 | 1k | https://www.seielect.com/catalog/sei-rmcf_rmcp.pdf | Resistor_SMD:R_0603_1608Metric | RMCF0603JJ1K00 | RMCF0603JJ1K00CT-ND | Stackpole Electronics Inc | RES 1K OHM 5% 1/10W 0603

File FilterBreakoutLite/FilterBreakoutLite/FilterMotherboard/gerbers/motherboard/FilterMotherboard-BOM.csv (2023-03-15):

Reference | Value | Package | Type | Datasheet | Description | Digikey Part Number | Manufacturer | MPN | Qty | Through QTY | SMT QTY
C1-C128 | 0.1uF | 0603 | SMT | https://media.digikey.com/pdf/Data%20Sheets/Samsung%20PDFs/CL10B104KC8NNNC_Spec.pdf | CAP CER 0.1UF 100V X7R 0603 | 587-6323-2-ND | Samsung | CL10B104KC8NNNC | 128 | 0 | 128
E1-E32 |  |  | SMT | https://media.digikey.com/pdf/Data%20Sheets/Hirose%20PDFs/UFL%20Series.pdf | RF Connectors / Coaxial Connectors U.FL RECEPTACLE SMT GLD M CONT REEL |  | Hirose | U.FL-R-SMT(10) | 32 | 0 | 32
J1-J8 |  |  | Through | https://www.molex.com/pdm_docs/sd/458440001_sd.pdf | CONN EDGE DUAL FEMALE 16POS GOLD | WM7543-ND | Molex | 458440004 | 8 | 8 | 0
J9, J17 |  | 2x32 | Through | https://suddendocs.samtec.com/prints/tsw-xxx-xx-x-x-xx-xxx-footprint.pdf | CONN HEADER VERT 64POS 2.54MM | SAM1028-32-ND | Samtec | TSW-132-07-G-D | 2 | 2 | 0
J10 |  | DB25 | Through | https://www.te.com/commerce/DocumentDelivery/DDEController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 | CONN D-SUB RCPT 25POS VERT SLDR | A144955-ND | TE Connectivity AMP Connectors | 748612-1 | 1 | 1 | 0
J12, J15, J18 |  | 2x2 | Through | http://suddendocs.samtec.com/catalog_english/tsw_th.pdf | CONN HEADER VERT 4POS 2.54MM | SAM1028-02-ND | Samtec | TSW-102-07-G-D | 3 | 3 | 0
J11, J13 |  | 3x32 | Through | http://suddendocs.samtec.com/catalog_english/tsw_th.pdf | CONN HEADER VERT 96POS 2.54MM | SAM12369-ND | Samtec | TSW-132-07-G-T | 2 | 2 | 0
J14, J16 |  | HD68 | Through | https://www.te.com/commerce/DocumentDelivery/DDEController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 | CONN D-TYPE RCPT 68POS R/A SLDR | A31814-ND | TE Connectivity AMP Connectors | 5787082-7 | 2 | 2 | 0
R1-R3 | 50 | 0603 | SMT | https://www.seielect.com/catalog/sei-rmcf_rmcp.pdf | RES 51 OHM 5% 1/10W 0603 | RMCF0603JT51R0CT-ND | Stackpole Electronics Inc | RMCF0603JT51R0 | 3 | 0 | 3
R4-R131 | 1k | 0603 | SMT | https://www.seielect.com/catalog/sei-rmcf_rmcp.pdf | RES 1K OHM 5% 1/10W 0603 | RMCF0603JJ1K00CT-ND | Stackpole Electronics Inc | RMCF0603JJ1K00 | 128 | 0 | 128
 |  |  |  |  |  |  |  |  |  | 18 | 291

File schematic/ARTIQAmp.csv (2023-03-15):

Reference | Quantity | Value | Datasheet | Availability | Description | Digikey Number | MPN | Manufacturer | Package | Type
ANT1 ANT2 ANT3 ANT4 ANT5 ANT6 ANT7 ANT8 ANT9 ANT10 ANT11 ANT12 ANT13 ANT14 ANT15 ANT16 ANT17 ANT18 ANT19 ANT20 ANT21 ANT22 ANT23 ANT24 ANT25 ANT26 ANT27 ANT28 ANT29 ANT30 ANT31 ANT32 | 32 |  | https://media.digikey.com/pdf/Data%20Sheets/Hirose%20PDFs/UFL%20Series.pdf | Y | U.FL Series 50 Ohm Receptacle | H9161TR-ND | U.FL-R-SMT(10) | Hirose |  | SMT
C1 C3 C5 C6 C11 C12 C13 C14 C16 C19 C20 C21 C24 C25 | 14 | 1u | https://www.samsungsem.com/kr/support/product-search/mlcc/CL31B105KCHNNNE.jsp | Y | CAP CER 1UF 100V X7R 1206 | 1276-1838-1-ND | CL31B105KCHNNNE | Samsung | 1206 | SMT
C2 C4 C8 C10 C15 C17 C18 C22 C23 C26 | 10 | 10u | https://www.chemi-con.co.jp/products/relatedfiles/capacitor/catalog/HXDRA-e.PDF | Y | CAP ALUM POLY HYB 10UF 63V SMD | 565-HHXD630ARA100MF80GCT-ND | HHXD630ARA100MF80G | United Chemi-Con | Radial, Can - SMD | SMT
C27 C30 C33 C36 C39 C42 C45 C48 C51 C54 C57 C60 C63 C66 C69 C72 C75 C78 C81 C84 C87 C90 C93 C96 C99 C102 C105 C108 C111 C114 C117 C120 | 32 | 1n | http://www.passivecomponent.com/wp-content/uploads/datasheet/WTC_MLCC_General_Purpose.pdf | Y | CAP CER 1000PF 100V X7R 0603 | 1276-1131-1-ND | CL10B102KC8NNNC | Samsung | 603 | SMT
C28 C29 C31 C32 C34 C35 C37 C38 C40 C41 C43 C44 C46 C47 C49 C50 C52 C53 C55 C56 C58 C59 C61 C62 C64 C65 C67 C68 C70 C71 C73 C74 C76 C77 C79 C80 C82 C83 C85 C86 C88 C89 C91 C92 C94 C95 C97 C98 C100 C101 C103 C104 C106 C107 C109 C110 C112 C113 C115 C116 C118 C119 C121 C122 | 64 | 0.1u | https://media.digikey.com/pdf/Data%20Sheets/Samsung%20PDFs/CL10B104KC8NNNC_Spec.pdf | Y | CAP CER 0.1UF 100V X7R 0603 | 1276-6807-1-ND | CL10B104KC8NNNC | Samsung | 603 | SMT
C7 C9 | 2 | 47u | https://industrial.panasonic.com/cdbs/www-data/pdf/RDE0000/ABA0000C1178.pdf | Y | CAP ALUM 47UF 20% 100V SMD | P124728CT-ND | EEE-FK2A470AV | Panasonic | Radial, Can - SMD | SMT
D1 D2 | 2 |  | https://www.taiwansemi.com/assets/uploads/datasheet/PU6BCH%20SERIES_C2110.pdf | Y | 25NS, 6A, 100V, ULTRA FAST RECOV | 1801-PU6BBHCT-ND | PU6BBH | Taiwan Semiconductor | DO-214AA, SMB | SMT
D3 D4 D5 D6 D7 D8 D9 D10 D11 D12 D13 D14 D15 D16 D17 D18 D19 D20 D21 D22 D23 D24 D25 D26 D27 D28 D29 D30 D31 D32 D33 D34 | 32 |  | https://assets.nexperia.com/documents/data-sheet/BAV99_SER.pdf | Y | X34 PB-F SWITCHING DIODE SOT23 | 264-BAV99LMTR-ND | BAV99,LM | Toshiba | SOT23 | SMT
FL1 FL2 FL3 FL4 FL5 FL6 FL7 FL8 FL9 FL10 FL11 FL12 FL13 FL14 FL15 FL16 FL17 FL18 FL19 FL20 FL21 FL22 FL23 FL24 FL25 FL26 FL27 FL28 FL29 FL30 FL31 FL32 | 32 |  | https://www.murata.com/en-eu/products/productdata/8796767059998/ENFE0003.pdf | Y | SMT EMI filter capacitor | 490-2554-2-ND | NFE61PT472C1H9L | Murata Electronics | 2706, 3 PC Pad | SMT
IC1 IC2 IC3 IC4 IC5 IC6 IC7 IC8 IC9 IC10 IC11 IC12 IC13 IC14 IC15 IC16 IC17 IC18 IC19 IC20 IC21 IC22 IC23 IC24 IC25 IC26 IC27 IC28 IC29 IC30 IC31 IC32 | 32 |  | http://cds.linear.com/docs/en/datasheet/6090fe.pdf | Y | IC OPAMP GP 1 CIRCUIT 8SOIC | 505-LTC6090CS8E#PBF-ND | LTC6090CS8E#PBF | Analog Devices Inc. | SOIC-8E | SMT
J1 J5 | 2 |  | https://www.te.com/commerce/DocumentDelivery/DDEController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 | Y | CONN D-TYPE RCPT 68POS R/A SLDR | A31814-ND | 5787082-7 | TE Connectivity AMP Connectors |  | Through
J2 J4 J6 | 3 |  | https://media.digikey.com/pdf/Data%20Sheets/Phoenix%20Contact%20PDFs/1935174.pdf | Y | TERM BLK 3POS SIDE ENTRY 5MM PCB | 277-1578-ND | 1935174 | Phoenix Contact |  | Through
J3 J7 J8 | 3 |  | https://suddendocs.samtec.com/catalog_english/tsm.pdf | Y | CONN HEADER SMD 4POS 2.54MM | SAM10780-ND | TSM-102-01-L-DV | Samtec Inc. |  | SMT
L1 L2 | 2 | 1m | https://media.digikey.com/pdf/Data%20Sheets/Taiyo%20Yuden%20PDFs%20URL%20links/CBC3225T102KR_SS.pdf | Y | FIXED IND 1MH 100MA 13 OHM SMD | 587-3214-2-ND | CBC3225T102KR | Taiyo Yuden | 1210 | SMT
L3 L4 L5 L6 L7 L8 L9 L10 L11 L12 L13 L14 L15 L16 L17 L18 L19 L20 L21 L22 L23 L24 L25 L26 L27 L28 L29 L30 L31 L32 L33 L34 | 32 | 18.4k | http://componentsearchengine.com/Datasheets/1/744229.pdf | Y | SMD Common Mode Line Filter WE-SL5 | 732-1488-1-ND | 744229 | Wurth Elektronik | Horizontal, 4 PC Pad | SMT
R1 R2 | 2 | 3k | https://www.vishay.com/docs/20043/crcwhpe3.pdf | Y | RES 3K OHM 5% 1W 2512 | RMCF2512JT3K00TR-ND | RMCF2512JT3K00 | Stackpole Electronics Inc | 2512 | SMT
R3 R8 R13 R18 R23 R28 R33 R38 R43 R48 R53 R58 R63 R68 R73 R78 R83 R88 R93 R98 R103 R108 R113 R118 R123 R128 R133 R138 R143 R148 R153 R158 | 32 | 100 | https://www.seielect.com/catalog/sei-rmcf_rmcp.pdf | Y | RES 100 OHM 1% 1/10W 0603 | RMCF0603FG100RCT-ND | RMCF0603FG100R | Stackpole Electronics Inc | 603 | SMT
R4 R6 R9 R11 R14 R16 R19 R21 R24 R26 R29 R31 R34 R36 R39 R41 R44 R46 R49 R51 R54 R56 R59 R61 R64 R66 R69 R71 R74 R76 R79 R81 R84 R86 R89 R91 R94 R96 R99 R101 R104 R106 R109 R111 R114 R116 R119 R121 R124 R126 R129 R131 R134 R136 R139 R141 R144 R146 R149 R151 R154 R156 R159 R161 | 64 | 4.99k | https://www.seielect.com/catalog/sei-rmcf_rmcp.pdf | Y | RES SMD 4.99K OHM 1% 1/10W 0603 | RMCF0603FT4K99CT-ND | RMCF0603FT4K99 | Stackpole Electronics Inc | 603 | SMT
R5 R10 R15 R20 R25 R30 R35 R40 R45 R50 R55 R60 R65 R70 R75 R80 R85 R90 R95 R100 R105 R110 R115 R120 R125 R130 R135 R140 R145 R150 R155 R160 | 32 | 1.65k | https://www.seielect.com/catalog/sei-rmcf_rmcp.pdf | Y | RES 1.65K OHM 1% 1/10W 0603 | RMCF0603FT1K65CT-ND | RMCF0603FT1K65 | Stackpole Electronics Inc | 603 | SMT
R7 R12 R17 R22 R27 R32 R37 R42 R47 R52 R57 R62 R67 R72 R77 R82 R87 R92 R97 R102 R107 R112 R117 R122 R127 R132 R137 R142 R147 R152 R157 R162 | 32 | 30 | https://www.seielect.com/catalog/sei-rmcf_rmcp.pdf | Y | RES 30 OHM 1% 1/10W 0603 | 738-RMCF0603FT30R0CT-ND | RMCF0603FT30R0 | Stackpole Electronics Inc | 603 | SMT

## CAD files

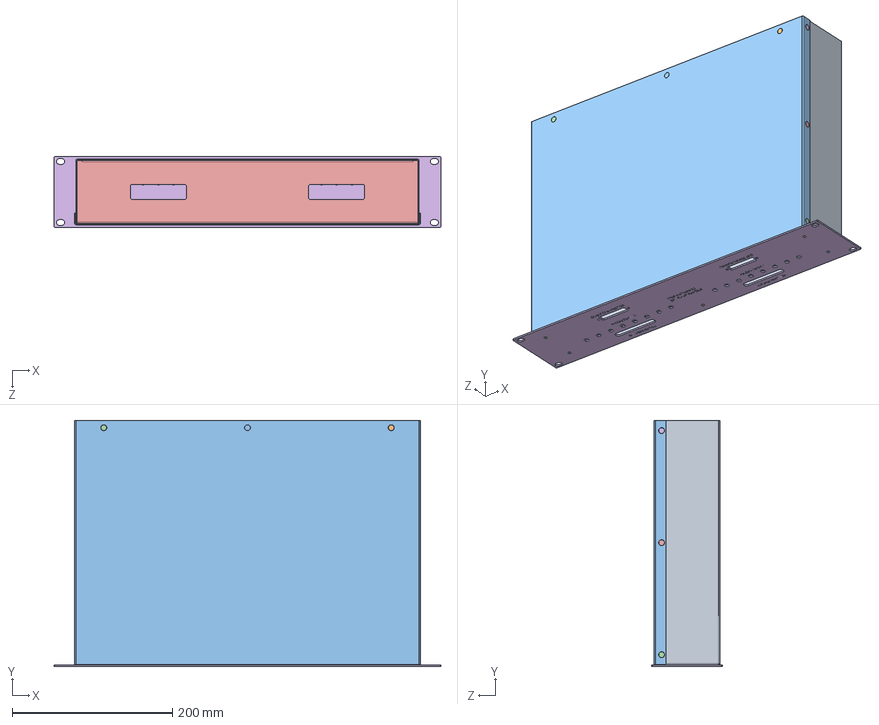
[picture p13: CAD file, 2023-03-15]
FilterBreakoutLite/FilterBreakoutLite/Enclosure CAD/protocase_enclosure/filter_breakout_v2.SLDASM
482.6 x 306.9 x 88.1 mm
chassis_edited
SP-632-1^filter_breakout_v2
SP-632-1-0^filter_breakout_v2
SP-632-1-1^filter_breakout_v2
SP-632-1-2^filter_breakout_v2
SP-632-1-3^filter_breakout_v2
SP-632-1-4^filter_breakout_v2
FH4-832-6^filter_breakout_v2
FH4-832-6-5^filter_breakout_v2
FH4-832-6-6^filter_breakout_v2
Cover(2)^filter_breakout_v2
6-32_1_4in_stainless_phillips_flathead_screw_100_deg^filter_breakout_v2
6-32_1_4in_stainless_phillips_flathead_screw_100_deg-7^filter_breakout_v2
6-32_1_4in_stainless_phillips_flathead_screw_100_deg-8^filter_breakout_v2
6-32_1_4in_stainless_phillips_flathead_screw_100_deg-9^filter_breakout_v2
6-32_1_4in_stainless_phillips_flathead_screw_100_deg-10^filter_breakout_v2
6-32_1_4in_stainless_phillips_flathead_screw_100_deg-11^filter_breakout_v2
6-32_1_4in_stainless_phillips_flathead_screw_100_deg-12^filter_breakout_v2
6-32_1_4in_stainless_phillips_flathead_screw_100_deg-13^filter_breakout_v2
6-32_1_4in_stainless_phillips_flathead_screw_100_deg-14^filter_breakout_v2
rear_edited
SP-632-1-15^filter_breakout_v2
SP-632-1-16^filter_breakout_v2
SP-632-1-17^filter_breakout_v2
FH4-832-6-18^filter_breakout_v2
FH4-832-6-19^filter_breakout_v2
FH4-832-6-20^filter_breakout_v2
FH4-832-6-21^filter_breakout_v2
FH4-832-6-22^filter_breakout_v2
front_edited

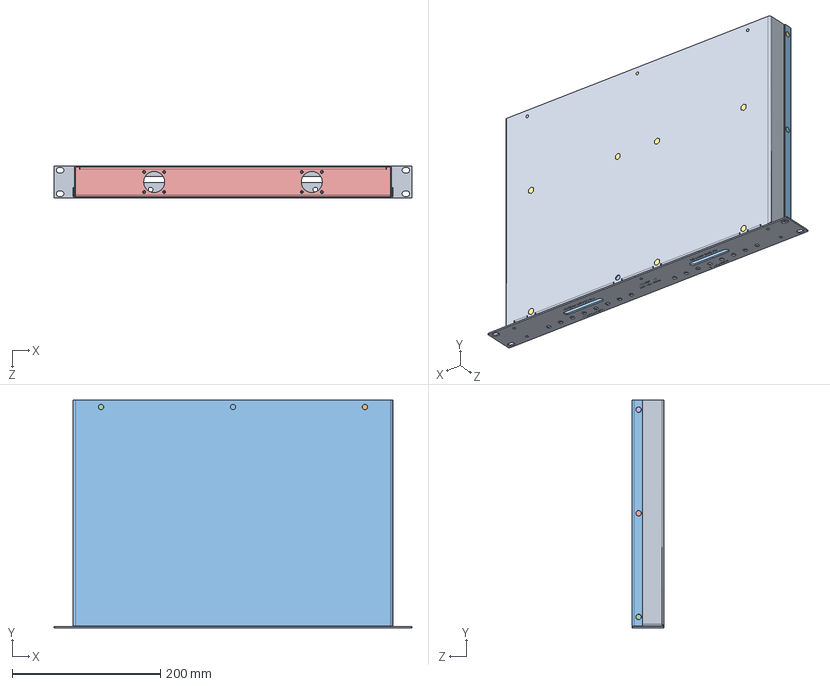
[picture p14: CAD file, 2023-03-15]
FilterBreakoutLite/FilterBreakoutLite/Enclosure CAD/filter_case_1U.SLDASM
482.6 x 306.7 x 43.7 mm
Chassis_1
S-632-1ZI
S-632-1ZI_6
S-632-1ZI_7
S-632-1ZI_3
S-632-1ZI_8
S-632-1ZI_5
FH-832-6ZI_7
FH-832-6ZI_4
FH-832-6ZI_3
6-32_1_4in_natural_phillips_flathead_screw_100_deg_7
6-32_1_4in_natural_phillips_flathead_screw_100_deg_3
6-32_1_4in_natural_phillips_flathead_screw_100_deg_2
6-32_1_4in_natural_phillips_flathead_screw_100_deg_9
6-32_1_4in_natural_phillips_flathead_screw_100_deg_6
6-32_1_4in_natural_phillips_flathead_screw_100_deg_5
6-32_1_4in_natural_phillips_flathead_screw_100_deg_8
6-32_1_4in_natural_phillips_flathead_screw_100_deg
6-32_1_4in_natural_phillips_flathead_screw_100_deg_4
Rear
S-632-1ZI_4
S-632-1ZI_2
S-632-1ZI_9
Front
FH-832-6ZI_6
FH-832-6ZI_2
FH-832-6ZI
FH-832-6ZI_5
FH-832-6ZI_8
BSO4-832-16-PennEngineering x 8
CLS-440-1-PennEngineering-3D-10-17-2022 x 8

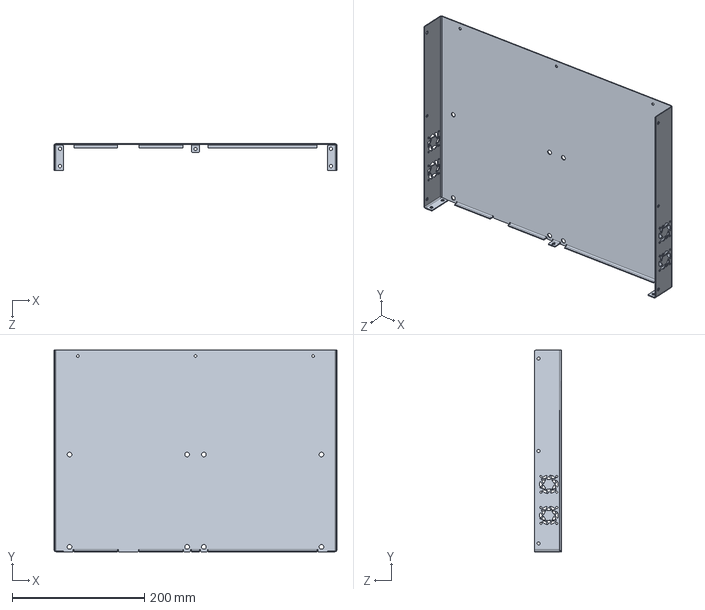
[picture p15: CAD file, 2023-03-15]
enclosure_CAD/Chassis_1.sldprt
428.0 x 304.8 x 40.5 mm

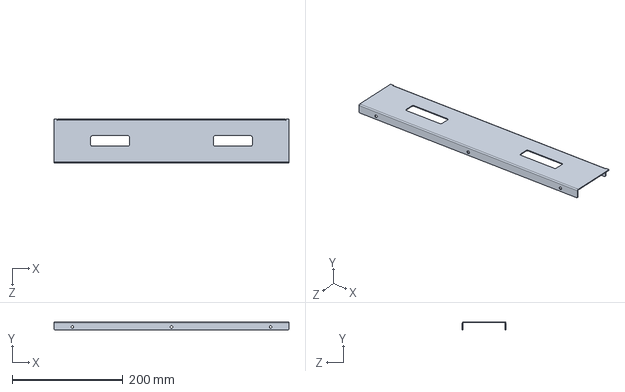
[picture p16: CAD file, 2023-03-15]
FilterBreakoutLite/FilterBreakoutLite/Enclosure CAD/rear_edited.SLDPRT
424.9 x 14.7 x 78.7 mm

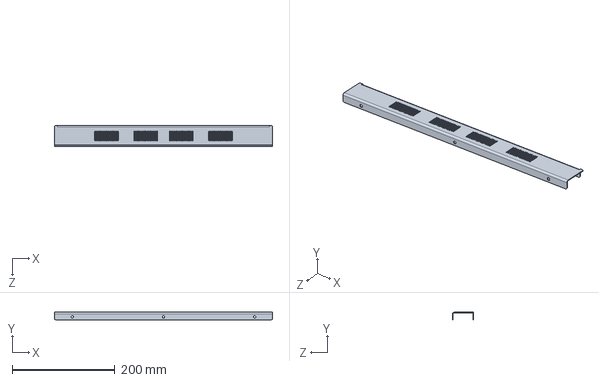
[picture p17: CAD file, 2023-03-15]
enclosure_CAD/Rear.sldprt
425.0 x 14.7 x 40.7 mm

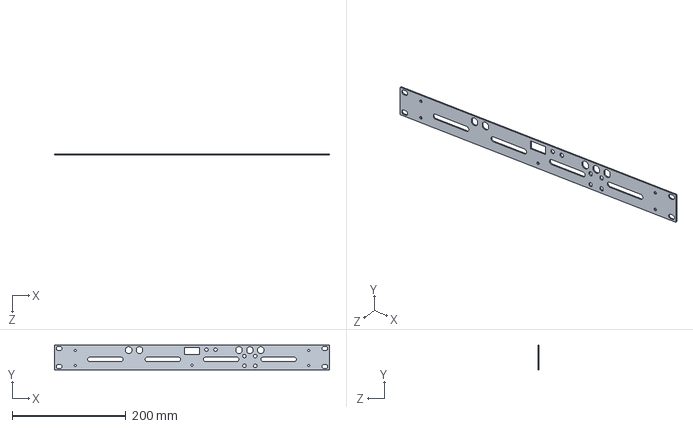
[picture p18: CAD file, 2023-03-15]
enclosure_CAD/Front.sldprt
482.6 x 43.7 x 1.90 mm

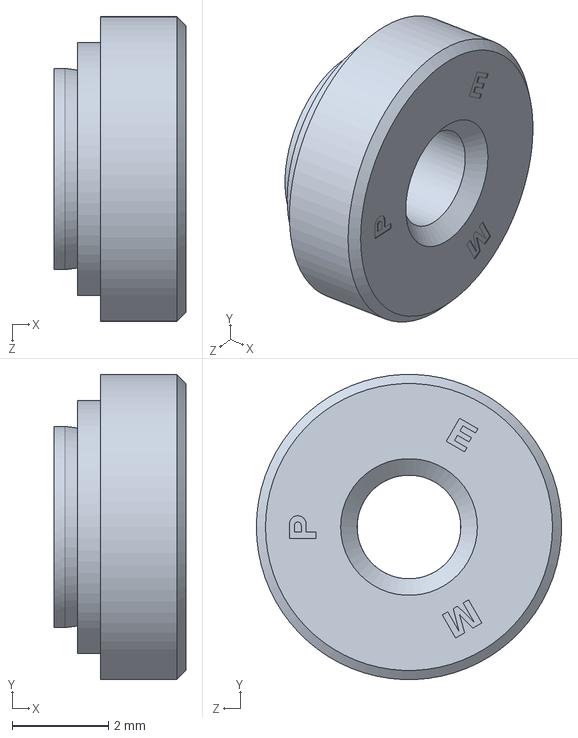
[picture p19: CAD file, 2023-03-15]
FilterBreakoutLite/FilterBreakoutLite/Enclosure CAD/CLS-440-1-PennEngineering-3D-10-17-2022.SLDPRT
2.74 x 6.34 x 6.35 mm

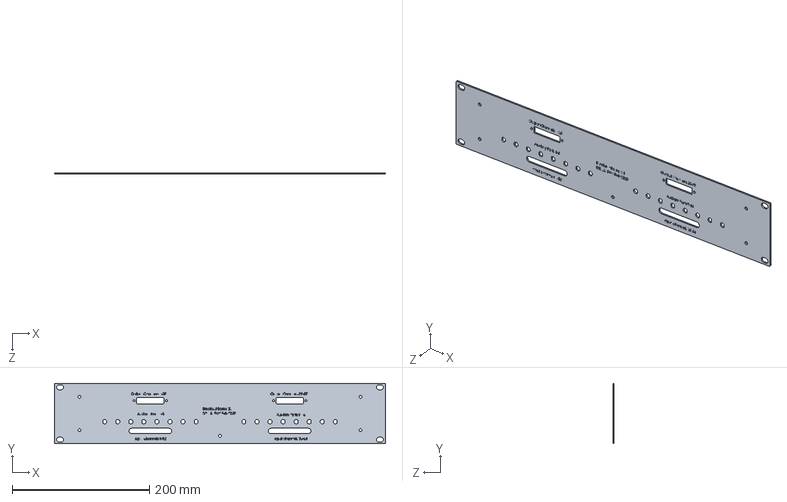
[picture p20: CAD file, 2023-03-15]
FilterBreakoutLite/FilterBreakoutLite/Enclosure CAD/front_edited.SLDPRT
482.6 x 88.1 x 2.06 mm

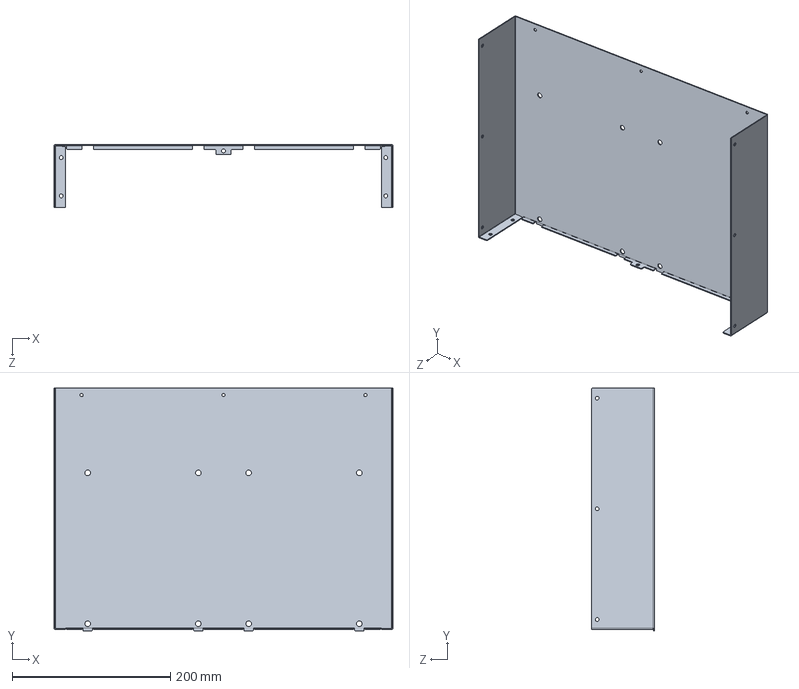
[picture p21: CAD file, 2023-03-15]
FilterBreakoutLite/FilterBreakoutLite/Enclosure CAD/chassis_edited.SLDPRT
428.0 x 306.4 x 79.9 mm

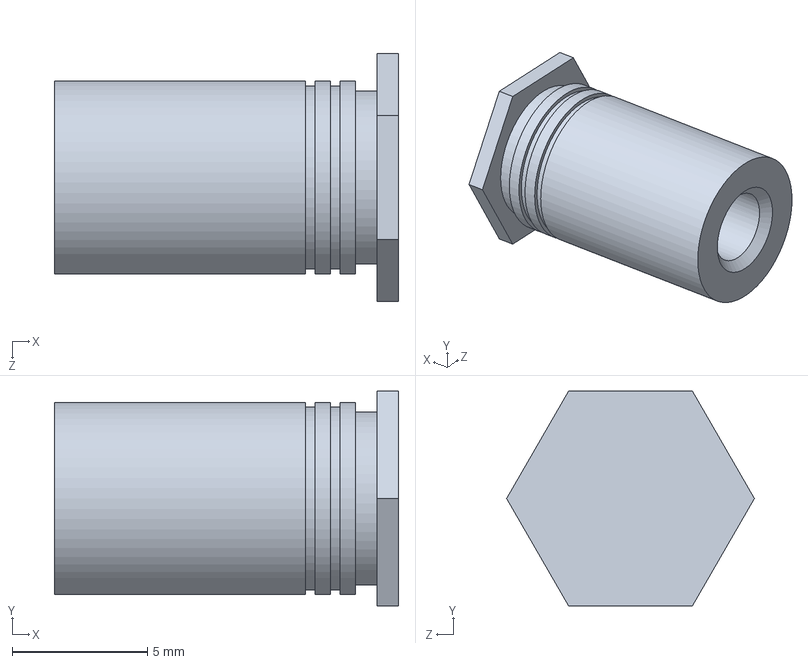
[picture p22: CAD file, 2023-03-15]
enclosure_CAD/BSO4-832-16-PennEngineering.SLDPRT
12.7 x 7.92 x 9.15 mm

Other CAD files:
enclosure_CAD/amp_case_slim.SLDASM
FilterBreakoutLite/FilterBreakoutLite/Enclosure CAD/protocase_enclosure/filter_case_1U Rev1(-).step
FilterBreakoutLite/FilterBreakoutLite/Enclosure CAD/filter_case_1U Rev(-).step
enclosure_CAD/Cover.sldprt
enclosure_CAD/FH-832-6ZI_6.sldprt
FilterBreakoutLite/FilterBreakoutLite/Enclosure CAD/Chassis_1_edited.SLDPRT
enclosure_CAD/S-632-1ZI_7.sldprt
enclosure_CAD/S-632-1ZI_9.sldprt
FilterBreakoutLite/FilterBreakoutLite/Enclosure CAD/filter_case_1U Rev(-).x_t
FilterBreakoutLite/FilterBreakoutLite/Enclosure CAD/protocase_enclosure/filter_case_1U Rev(-).x_t
enclosure_CAD/6-32_1_4in_natural_phillips_flathead_screw_100_deg.sldprt
enclosure_CAD/6-32_1_4in_natural_phillips_flathead_screw_100_deg_2.sldprt
enclosure_CAD/6-32_1_4in_natural_phillips_flathead_screw_100_deg_3.sldprt
enclosure_CAD/6-32_1_4in_natural_phillips_flathead_screw_100_deg_4.sldprt
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

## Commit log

2019-03-23 Re-adding the KiCAD project file because I am a git chimp
    [ARTIQAmp.kicad_pcb, ARTIQAmp.sch]
2019-03-23 Noodled around with KiCAD and added project-specific library
    [ARTIQAmp.sch]
2019-03-23 Added schematic, library and datasheets
    [ARTIQAmp.sch, AmpBlock.sch, Bill of Materials-Zotino.xlsx]
2019-03-23 Added connectors to the library and made an array of lots of amps
    [ARTIQAmp.sch, AmpBlock.sch]
2019-04-01 Started adding footprints to library and started working on the layout of the amplifier block
    [AmpBlock.kicad_pcb, AmpBlock.sch]
2020-02-29 Test a dumb little edit from the linux machine on campus
    [ARTIQAmp.sch, AmpBlock.sch]
2020-03-02 Add schematic for the Fastino to the docs
2020-03-08 Add the schematic for the old amplifier
2020-03-09 Add power connections; assign footprints to all components
    [ARTIQAmp.sch, AmpBlock.sch]
2020-03-09 Started layout
    [ARTIQAmp.kicad_pcb, AmpBlock.sch]
2020-09-19 Update libraries for new components
    [ARTIQAmp.kicad_pcb, AmpBlock.sch]
2020-09-19 Initial updates to schematic with new components
    [AmpBlock.sch]
2020-09-19 Add a new footprint and update gitignore
2020-09-20 finalize schematic and start organizing components in layout
    [ARTIQAmp.kicad_pcb, ARTIQAmp.sch, AmpBlock.sch]
2020-09-20 Small edit to position of some components
    [ARTIQAmp.kicad_pcb]
2020-09-27 Updating with recent changes as layout work starts
    [ARTIQAmp.kicad_pcb, ARTIQAmp.sch, AmpBlock_Flipped.sch]
2020-09-28 More layout routing
    [ARTIQAmp.kicad_pcb]
2020-10-02 Complete initial layout and swap components around in schematic
    [ARTIQAmp.kicad_pcb, ARTIQAmp.sch, AmpBlock.sch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]
2020-10-06 Saftey commit while removing internal layers
    [ARTIQAmp.kicad_pcb]
2020-10-09 Board updates and starting to add more capacitors
    [ARTIQAmp.kicad_pcb, ARTIQAmp.sch, AmpBlock.sch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]
2020-10-22 Many updates to layout; nearing final design
    [ARTIQAmp.kicad_pcb, ARTIQAmp.sch, AmpBlock.sch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]
2020-10-26 Penultimate tweaks
    [ARTIQAmp.kicad_pcb, ARTIQAmp.sch, AmpBlock.sch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]
2020-10-26 Saftey commit before adding new shorting resistors
    [ARTIQAmp.sch, AmpBlock.sch, AmpBlock_Flipped.sch]
2020-10-27 Design complete
    [ARTIQAmp-B_Cu.gbl, ARTIQAmp-B_Mask.gbs, ARTIQAmp-B_SilkS.gbo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]
2020-10-27 Update gerbers to remove rogue hole
    [ARTIQAmp-B_Cu.gbl, ARTIQAmp-B_Mask.gbs, ARTIQAmp-B_SilkS.gbo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]
2020-10-28 Update fab specs and add CAD to gitignore
2022-10-06 Major Rework incorporating u.FL pickoffs, safety diodes, and extra capacitance
    [ARTIQAmp-B_Cu.gbl, ARTIQAmp-B_Fab.gbr, ARTIQAmp-B_Mask.gbs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]
2022-10-07 CAD for a case sized to work with these boards.
2023-01-26 Adding Info for a filter extension module.
2023-03-15 Update board design to better support enclosure with fan connect and diode connect headers. Also widen differential choke land pads and include enclosure CAD.
    [6-32_1_4in_natural_phillips_flathead_screw_100_deg.sldprt, 6-32_1_4in_natural_phillips_flathead_screw_100_deg_2.sldprt, 6-32_1_4in_natural_phillips_flathead_sc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]
2023-03-15 filter box changes
    edited the filter box to make it 2u and added cutouts for the outputs on the front and back panels.
    [6-32_1_4in_natural_phillips_flathead_screw_100_deg.sldprt, 6-32_1_4in_natural_phillips_flathead_screw_100_deg_2.sldprt, 6-32_1_4in_natural_phillips_flathead_sc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]
2023-03-27 Better gitignore for CAD
